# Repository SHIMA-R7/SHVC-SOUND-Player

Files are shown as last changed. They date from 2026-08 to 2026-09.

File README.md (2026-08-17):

# SHVC-SOUND スタンドアロンプレイヤー

Arduino Uno R3 / Nano (ATmega328P・5Vロジック) で SHVC-SOUND(スーファミ音源モジュール: S-SMP + S-DSP + ARAM + DAC)を駆動し、
`.spc` ファイルを実チップで再生するプロジェクト。音声は TDA7053A(ステレオBTL)で増幅し3.5mmジャックへ出力する。

## 構成

| ディレクトリ | 内容 |
|---|---|
| `SHVC-SOUND-KiCad_project/` | 基板設計(KiCad)。スキーマ・PCB・カスタムフットプリント |
| `SHVC-SOUND_python/` | 再生ソフト一式 |
| `SHVC-SOUND_python/spc_gui.py` | **GUIアプリ**(Tkinter製)。プレイリスト再生・音量調整・ROM解析 |
| `SHVC-SOUND_python/spc_play.py` | PC側。`.spc` を解析しシリアル経由でArduinoへ転送する(CLI/GUI共用) |
| `SHVC-SOUND_python/rom_tools.py` | スーファミROMの内部ヘッダ解析(マッパ判別・チェックサム検証) |
| `SHVC-SOUND_python/spc_uploader/` | Arduino側。シリアルコマンドをSPC700 IPL ROMプロトコルへ変換する |
| `SHVC-SOUND_python/hw_selftest/` | Arduino単体で動く自己診断。PCなしでノイズを鳴らして配線を検証する |
| `docs/minimal-bringup.md` | 最小構成での実機立ち上げ手順と配線表 |

## まず実機で音を確認する

いきなり `spc_play.py` を試す前に、アンプと12V系を外した最小構成で
`hw_selftest/hw_selftest.ino` を走らせる。ハードの問題か転送ソフトの問題かが一発で切り分けられる。
手順と配線表は [docs/minimal-bringup.md](docs/minimal-bringup.md) を参照。

## GUIアプリ

```bash
python spc_gui.py
```

- プレイリストに `.spc` をまとめて登録して再生。ID666タグ(曲名・ゲーム・作曲者)を表示
- DSP音量倍率とアンプPWM音量をスライダーで調整
- 転送はワーカースレッドで実行され、進捗バーとログをリアルタイム表示。中止も可能
- **フォルダ監視**: エミュレータのSPC出力先を指定しておくと、新しくダンプされた
  `.spc` を自動でプレイリストに追加する
- ROM解析タブ: 吸い出したROMのタイトル・マッパ(LoROM/HiROM/ExHiROM)・容量・
  リージョン・チェックサムを表示

### ROMからのSPC抽出について

**ROMの中に `.spc` は入っていない**ため、直接抽出はできない。
`.spc` はSPC700が曲を再生中の ARAM 64KB + DSPレジスタ + CPUレジスタの
スナップショットであり、ROMにあるのはサウンドドライバ・BRRサンプル・
シーケンスデータがバラバラに格納されたもの。ARAMの完成イメージは
ゲームを実際に起動して初めて組み上がる。

実用的な手順は、SPCダンプ機能を持つエミュレータ(Mesen2、bsnes/higan、
一部のSnes9xビルド)でROMを動かし、曲の再生中にダンプすること。
出力先をGUIの「フォルダを監視」に指定しておけば、ダンプした瞬間に
プレイリストへ入って実機で鳴らせる。

## CLIでの使い方

Arduino IDE で `spc_uploader/spc_uploader.ino` を書き込み、以下を実行する。

```bash
python spc_play.py COM3 song.spc
```

`pyserial` が必要:

```bash
pip install pyserial
```

診断用フラグ: `--test`(強制ノイズ再生)、`--skip-bulk`、`--low-addr`、`--only-stub`

## 配線 (Arduino ⇔ SHVC-SOUND 24pin)

| Arduino | SHVC-SOUND pin | 信号 |
|---|---|---|
| D2-D9 | 7-14 | D0-D7 |
| A0 | 3 | A0 |
| A1 | 4 | A1 |
| A2 | 5 | /WR |
| A3 | 6 | /RD |
| A4 | 15 | /RESET |
| D10 | 20 | /MUTE(常時HIGH固定) |
| - | 2 / 1 | CS→+5V / /CS→GND 直結 |
| - | 18, 24 | VCC, VS → +5V |
| - | 19, 23 | GND |
| - | 21, 22 | Audio-L / Audio-R → アンプ入力 |

ロジック系(5V)とアンプ系(12V)は別電源。Arduinoのレギュレータからアンプ用12Vを取らないこと。

## 既知の問題

- **復元スタブが曲データを上書きする**: `spc_play.py` のDSP復元スタブは約800バイトあり `$FFC0` 直下(≒`$FC9B`)に配置されるが、
  この領域はメインRAM転送範囲(`$0100-$FFBF`)と重なるため曲データを約800バイト破壊する。
  この領域をサンプルやエコーバッファに使う曲ではノイズが出る。エコーバッファ領域への配置か、スタブのループ化による小型化が要検討。
- **基板のDRC違反が未修正**: シルク重なり2件、シルクが銅箔にかかる6件、フットプリント型不一致1件、ライブラリ不一致1件。
- 実機での動作確認は未完了。
- **基板のSHVC-SOUNDフットプリントに1番ピンの表示が無い**: `SHVC-SOUND-MB.kicad_mod` は
  パッド24個すべてが丸、シルクにピン番号も1番マーカーも無い(リファレンス指定子のみ)。
  コネクタ自体にキーが無く逆挿しできてしまうため、シルクに `1` の印字と極性マークを追加すべき。
- **基板はArduino Nanoフットプリント**(`Module:Arduino_Nano_WithMountingHoles`)。
  Uno R3はピン互換だがフットプリントが合わないため、基板に載せる場合は要変更。ジャンパ配線での検証には支障なし。

## ライセンス / 帰属

基板設計の一部は [OpenSFC](https://github.com/starlightk7/OpenSFC)(© 2025 starlightk7、CERN-OHL-S)に由来する。
詳細と再頒布時の義務は `SHVC-SOUND-KiCad_project/SHVC-SOUND-KiCad/THIRD_PARTY_NOTICE_OpenSFC.txt` を参照。
公開・頒布する場合は CERN-OHL-S 3.3 に従い、改変内容の要約を同NOTICEに追記すること。

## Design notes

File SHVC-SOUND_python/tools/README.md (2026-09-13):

# tools — 実機向けの補助ツール

`spc_realtime.ino` を書き込んだ Arduino + SHVC-SOUND で使う。
いずれも `SHVC-SOUND_python` の `midi2spc` / `spc_play` を読み込むので、このフォルダに置いたまま実行する。

## 録音をそのまま鳴らす(BRRストリーミング)

| ツール | 内容 |
|---|---|
| `pcm_stream.py` | 録音をBRRに変換し、ARAMのリングバッファへ書き足しながら最後まで鳴らす。`--loop-whole` で短い音声をS-DSPだけでループ。`--selftest` でSPC700側ドライバをシミュレータ検証 |
| `pcm_clip_test.py` | ARAMに収まる数秒だけを一括転送して鳴らす(実現性確認用) |
| `zundamon_talk.py` | VOICEVOX(ずんだもん)でセリフを合成し、`pcm_stream.py --loop-whole` で鳴らす |
| `morning_call.py` | 指定時刻にモーニングコール → 曲のストリーミング再生(待機中はアイドルスリープを抑止) |

```bash
python pcm_stream.py song.wav --rate 8000 --peak 0.8
```

仕組み: ARAM `$0400-$FEFA` をBRRのリングバッファにし、ボイス0がバッファ末尾(loop+end)で先頭へ戻り続ける。
SPC700上のドライバ(`PCM_DRIVER`、IPLで `$0200` へ転送)は、ホストの `$F4` の変化を合図に `$F7` のコマンドで分岐する。

| `$F7` | 動作 |
|---|---|
| 0 | DSPレジスタ書き込み(`$F5`=レジスタ, `$F6`=値) |
| 1 / 2 | 1 / 2バイトをリングバッファへ書き、ポインタ(`$02-$03`)を進める |
| 3 | ポインタを返す |
| 4 | DSPレジスタ読み出し |
| 5 | ポインタ設定(起動直後、IPLジャンプの残りポート値を指示と誤認して1回書いてしまうので必ず合わせ直す) |
| 6 | ポインタ位置の1バイトを返す(読み返し検査用) |

Arduino側コマンド: `CMD_PCMCHUNK`(0x0C) / `CMD_DRVQUERY`(0x0D) / `CMD_DRVPEEK`(0x0E)。

注意: `midi2spc/brr.py` の予測フィルタの丸めは実機S-DSPと完全には一致しない。長い録音では `--filter0`(予測なし)も選べる。

VOICEVOXエンジンはリポジトリに含めない。`tools/voicevox_engine/` に展開するか、`--engine-dir` / 環境変数 `VOICEVOX_ENGINE_DIR` で場所を指定する。
音声を公開する場合はクレジット「VOICEVOX:ずんだもん」が必要。

## 自動採譜・MIDIの整理

| ツール | 内容 |
|---|---|
| `midi_reduce.py` | トラックを選んでチャンネル・音色を振り直す(オーケストラ譜の書き出し向け) |
| `separate_transcribe.py` | Demucsでパート分離 → Basic Pitchでパートごとに採譜(チューニング補正つき) |
| `score_transcribe.py` | 拍の升目にそろえてメロディ・和音・ベースを起こす |
| `vocal_melody.py` | 分離したボーカルからpYINで主旋律を取る |
| `midi_arrange.py` / `midi_thin.py` | 採譜結果をメロディ/和音/ベースに整理 / 重ねと音数を間引く |

楽器演奏の録音ならそこそこ使えるが、歌入りのポップスや合唱は崩れやすい。
必要なもの: basic-pitch(ONNX), librosa, pretty_midi, demucs + torch(CPU), soundfile。

## 診断

| ツール | 内容 |
|---|---|
| `port_probe.py` | リセット前後の `$F4-$F7` を読む(配線の化けの確認) |
| `probe_retry.py` | 正常な値が読めるまで繰り返す |

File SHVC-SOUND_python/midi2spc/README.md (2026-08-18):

# midi2spc — MIDIをSHVC-SOUND(SPC700 / S-DSP)で鳴らす

MIDIファイルを、スーファミ音源(S-DSP)の制約に落とし込んで演奏するツール。
**PC上のソフトウェアモデル**でも、**実機のSHVC-SOUND**でも鳴らせる。

## 使い方(GUI)

配布用の実行ファイルは `dist/MIDI-to-SHVC-SOUND.exe`。Pythonのインストールは不要。

ソースから起動する場合:

```bash
python midi_gui.py
```

タブ構成:

- **変換・再生** — MIDIを選んで「変換」、そのまま再生 / WAV保存。音量倍率などの設定もここ
- **DSPイベント** — 変換結果として S-DSP に送るレジスタ操作の時系列を一覧表示
- **音色バンク** — BRRサンプルの一覧。選んで「試聴」でドレミが鳴る

起動時に音色バンクのBRRエンコード(十数秒)が走る。終わるまで「変換」は押せない。

exeを作り直すとき:

```bash
python -m PyInstaller --noconfirm --onefile --windowed --name "MIDI-to-SHVC-SOUND" --collect-all sounddevice midi_gui.py
```

## 使い方(コマンドライン)

```bash
python -m midi2spc song.mid
```

```bash
python -m midi2spc song.mid -o out.wav
```

```bash
python -m midi2spc song.mid --dump-events
```

```bash
python -m midi2spc --list-instruments
```

主なオプション:

| オプション | 意味 |
|---|---|
| `-o FILE` | WAVに書き出す(省略時はその場で再生) |
| `--master N` | ボイス音量の全体倍率 0.0-1.0(既定 0.55)。和音が多い曲で歪むなら下げる |
| `--gain N` | 出力全体のゲイン |
| `--tail N` | 曲末尾に足す余韻の秒数 |
| `--dump-events [N]` | S-DSPに送るイベント列を表示 |
| `--no-audio` | 音を出さず変換だけ確認 |

必要なもの: `numpy`(必須)、`sounddevice`(その場で再生する場合のみ)。

## 実機で鳴らす

### 1. Arduinoにファームウェアを書き込む

`spc_realtime/spc_realtime.ino` を書き込む。これは `spc_uploader.ino` の**上位互換**で、
従来の .spc 転送コマンドもそのまま残っているので `spc_gui.py` / `spc_play.py` も
このファームのまま動く。ピン配置は従来と同一。

```bash
arduino-cli compile --fqbn arduino:avr:nano spc_realtime
arduino-cli upload -p COM3 --fqbn arduino:avr:nano spc_realtime
```

### 2. 鳴らす

GUIの「実機で再生」欄でシリアルポートを選び、変換後に「実機へ転送して再生」。
コマンドラインなら:

```bash
python -m midi2spc song.mid --port COM3
```

### 実機再生時に起きること

1. SPC700をリセットしてIPL ROMの転送モードに入る
2. BRRサンプル(約13KB)・サンプルディレクトリ・常駐ドライバをARAMへ転送
3. 常駐ドライバへジャンプ
4. DSPを初期化(エコー無効・DIR設定・マスター音量)
5. レジスタ書き込みイベントをArduinoへストリーム送信

ARAMのメモリマップ:

| アドレス | 内容 |
|---|---|
| `$0200-$0216` | 常駐ドライバ(23バイト) |
| `$0300-$034F` | サンプルディレクトリ(1音色4バイト × 20) |
| `$0400-$3900` | BRRサンプル本体(約13KB) |

### 常駐ドライバ(23バイト)

S-DSPのレジスタはSPC700からしか触れず、ホスト(Arduino)から見えるのは
`$F4-$F7` の4バイトの窓だけ。そこで「`$F5`のレジスタ番号と`$F6`の値をDSPへ
書き写すだけ」のループをSPC700に常駐させ、Arduinoはその窓越しに指示を出す。

```asm
        clrp                    ; ダイレクトページを$00xxに固定
        mov  x,#$00
        mov  $F4,x              ; ACKラッチを初期化
loop:   cmp  x,$F4              ; ホストからの新しい指示待ち
        beq  loop
        mov  x,$F4              ; 新しいシーケンス値
        mov  a,$F5              ; DSPレジスタ番号
        mov  $F2,a              ;   -> DSPADDR
        mov  a,$F6              ; 書き込む値
        mov  $F3,a              ;   -> DSPDATA
        mov  $F4,x              ; ACK(シーケンス値を返す)
        bra  loop
```

曲の解釈はすべてPC側に残るので、SPC700側はこれで足りる。
**音楽ドライバをアセンブリで書く必要はない**のがこの構成の要点。

### 演奏タイミング

発音タイミングはArduinoが持つ。PCは4バイトのレコード
`[待ち時間LE16(100µs単位)][レジスタ番号][値]` を送り、Arduinoは48段の
リングバッファに積んで `micros()` で時刻どおりに実行する。待ち時間は
前のイベントの**予定時刻**から積み上げるので、誤差が累積してテンポがずれない。

PCが送りすぎないよう、Arduinoは1レコード消化するごとにクレジットバイトを返す。
PCは32レコードまで先行送信できる(Arduinoの受信バッファ64バイトとリングバッファ
48段の両方に収まる値)。

## 設計

```
song.mid
   │  smf.py          SMFパーサ(依存ライブラリなし)      ← midi_gui.py / __main__.py が呼ぶ
   ▼
MIDIイベント列
   │  engine.py       ★変換の本体
   ▼
S-DSPレジスタ操作イベント列
   │
   ├─ render.py       S-DSPのソフトウェアモデル → PCで音を出す
   └─ hardware.py     Arduino経由で実チップを鳴らす
```

`engine.py` が出すのは「どのボイスに、どのサンプルを、どのピッチ・音量・ADSRで
キーオンするか」という時系列で、これは実機のS-DSPレジスタ書き込みと1対1に対応する。
つまり `render.py` を差し替えれば、同じ変換結果をそのままハードウェアに流せる。

音色(`instruments.py`)も飾りではなく、実際に **BRR(4bit ADPCM)にエンコードして
デコードし直した波形**を鳴らしている。実機に載せるときはこの `brr_data` を
そのままARAMへ転送すればよい。バンク全体で約14KB、64KBのARAMに十分収まる。

## 再現していること / していないこと

再現している:

- BRRによる4bit量子化(実機と同じ量子化ノイズが乗る)
- 32kHz固定のサンプルレートと4タップ補間による高音のなまり
- **同時発音8ボイス**の制限と、足りないときの音の奪い合い
- 14bit PITCHレジスタ、ADSRエンベロープ、符号付き8bitのVOLL/VOLR
- MIDI側は NoteOn/Off、プログラムチェンジ、CC7/CC10/CC11/CC64、ピッチベンド、テンポチェンジ

再現していない(意図的な簡略化):

- サイクル精度のDSP動作(合成は「ノート単位」でまとめて行う)
- エコー / FIRフィルタ / ピッチモジュレーション / ノイズジェネレータ
- 補間テーブルは実機の512エントリ表そのものではなくガウス窓による近似
- ADSRのDECAY/SUSTAINは、実機の「周期ごとに `env -= (env>>8)+1`」を
  1サンプルあたりの減衰係数に直した閉じた形で計算している(形は同じ)

## テスト

```bash
python test_midi2spc.py
```

43件。実機がなくても確かめられるところを固めてある。特に常駐ドライバは
手でアセンブルした生バイト列なので、簡易SPC700シミュレータ(テスト内に同梱)で
実際に実行して、ACKハンドシェイク・シーケンス値の一周・キーオン1音ぶんの
レジスタ列が正しく届くことを検証している。

**実機での再生は2026-08-18に確認済み。** Arduino Uno + SHVC-SOUND で
rydeen.mid(9240ノート / 約4分半 / DSPレジスタ書き込み120120回)が
最後まで正常に再生できた。

## 実機で音が出ないときの切り分け

1. `spc_gui.py` で .spc が再生できるか — できなければ配線かバスタイミングの問題で、
   MIDI側とは無関係
2. GUIのログで「ドライバへジャンプ」の後にエラーが出るか —
   `常駐ドライバが応答しません` なら、ジャンプ自体かドライバの動作の問題
3. 転送は通るのに無音 — DSPの初期化(FLGのミュート解除、マスター音量)か、
   BRRサンプルのディレクトリ位置(`DIR`レジスタ)を疑う
4. 音は出るがノイズまみれ — エコーがARAMのサンプル領域を上書きしている可能性。
   `initial_dsp_writes()` がFLGのbit5(エコー書き込み禁止)を立てているか確認する

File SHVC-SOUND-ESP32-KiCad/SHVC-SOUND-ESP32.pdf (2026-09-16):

1 | 2 | 3 | 4 | 5 | 6 | 7 | 8
1 | 2 | 3 | 4 | 5 | 6 | 7 | 8

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
Size: A3 | Rev: 0.1 | F Date:
KiCad E.D.A. 10.0.6 | Id: 1/1

## Title: SHVC-SOUND Player ESP32

File: SHVC-SOUND-ESP32.kicad_sch

Sheet: /

C7

470n C6
470n

V+ 1 GND 2

J3

12V in (USB-PD)

C1
100u R6
10k | C3

100n

R1
330
SLEEVE 1 | RING
2 | RING_SW
3 | TIP

4
TIP_SW

5

# J1 PJ-324M

R8
10k

R10

10 C11

470u | R2

330 GND 1
VCC 2
A0 3
A1 4 | WR 5 | RD 6 | D0 7 | D1 8 | D2 9 | D3 10 | D4 11 | D5 12 | D6 | 13 D7 | 14 RESET | 15 NC | 16 NC | 17
VCC | 18 GND | 19 MUTE | 20
AUDIO_L | | 21
AUDIO_R | 22 GND | 23
VCC | | 24

J4

SHVC-SOUND module

C12
100u | R5
5.6k | C5 10u

R7
10k | OE1 1

A1 2
A2 3
A3 4
A4 5
A5 6
A6 7
A7 8
A8 9 | GND 10
Y8 | 11 Y7 | 12 Y6 | 13 Y5 | 14 Y4 | 15 Y3 | 16 Y2 | 17 Y1 | 18 OE2 19
VCC 20 | U2
74HCT541N (data write) | C8
100n C10

100n

EN 1
IO36 2
IO39 3
IO34 4
IO35 5
IO32 6
IO33 7
IO25 8
IO26 9
IO27 10
IO14 11
IO12 12
IO13 13 GND 14

VIN 15

IO23 | | 16
IO22 | | 17
TX0/IO1 | 18 RX0/IO3 | 19
IO21 | | 20
IO19 | | 21
IO18 | | 22
IO5 | | 23
TX2/IO17 | 24 RX2/IO16 | 25
IO4 | | 26
IO2 | | 27
IO15 | 28 GND | 29
3V3 | 30 U1

ESP32 DevKit V1 (30pin)

R9

# 10k DIR 1

A1 2
A2 3
A3 4
A4 5
A5 6
A6 7
A7 8
A8 9 | GND 10 | B8 | 11 B7 | 12 B6 | 13 B5 | 14 B4 | 15 B3 | 16 B2 | 17 B1 | 18 OE 19
VCC 20 | U4
74LVC245N (data read, DIR=B->A) | C2
100u C4

220u P1 1
VC_A 2 P3 3

IN_A 4
VP 5
IN_B 6 | GND 7
VC_B 8 | OUT_A | 9 GND | 10 P11 | 11 GND | 12 GND | 13 GND | 14 P15 | 15 OUT_B | 16 U6

TDA7053A C13

10u OE1 1

A1 2
A2 3
A3 4
A4 5
A5 6
A6 7
A7 8
A8 9 | GND 10
Y8 | 11 Y7 | 12 Y6 | 13 Y5 | 14 Y4 | 15 Y3 | 16 Y2 | 17 Y1 | 18 OE2 19
VCC 20 | U3
74HCT541N (control) | +VIN 1 | GND 2
VOUT | 3 U7 M78AR05-0.5 C9
100n | D1
1N5819

# GND +5V SHVC_D6

SHVC_D7

SHVC_RESET AUDIO_L AUDIO_R | AMP_IN_R

AMP_VC

AMP_IN_L AUDIO_L AMP_IN_L | AUDIO_R | AMP_VP +12V GND +12V | AMP_VC GND

# A1_3V3 D1_3V3 D0_3V3 GND +5V GND

RESET_3V3
VOL_PWM
RD_3V3 +5V | D3_3V3 D2_3V3 OE_W

# GND +3V3 WR_3V3 D7_3V3 D6_3V3 D5_3V3 D4_3V3

A0_3V3 | OE_R

D7_3V3 +5V GND

GND OE_R

# D0_3V3 D1_3V3 D2_3V3 D3_3V3 D4_3V3 D5_3V3 D6_3V3 D7_3V3 +3V3

SHVC_D0

SHVC_D2
SHVC_D3
SHVC_D4
SHVC_D5
SHVC_D6
SHVC_D7 | +5V GND

GND

SHVC_A1

SHVC_A0 +3V3

SHVC_D3
SHVC_D4

# SHVC_D5 +5V GND

SHVC_WR
SHVC_RD
SHVC_D0
SHVC_D1
SHVC_D2

SHVC_A0
SHVC_A1
SHVC_WR

SHVC_D1

SHVC_RESET GND RESET_3V3 | D1_3V3 OE_R | +3V3 | GND

SHVC_D0
SHVC_D1
SHVC_D2

SHVC_D3 +5V D2_3V3 D3_3V3 D4_3V3 D5_3V3 D6_3V3 OE_W

GND

D0_3V3

SHVC_D4
SHVC_D5
SHVC_D6
SHVC_D7

# SHVC_RD +3V3 OE_W +3V3

AMP_OUT_R

GND

GND | OUT_L_RC

GND
JACK_L

# JACK_R JACK_L AMP_OUT_L OUT_L_RC

GND

GND

AMP_OUT_L GND | OUT_R_RC | JACK_R AMP_OUT_R | OUT_R_RC GND AMP_VP GND | AMP_VP VOL_PWM

AMP_VP
AMP_IN_R
GND
AMP_VC AMP_VC GND +12V | +5V GND +12V | AMP_VC

GND

# GND +5V GND

A0_3V3

A1_3V3 WR_3V3 RD_3V3 RESET_3V3 GND

GND | GND +5V GND

GND

REG_5V +5V REG_5V | +5V SHVC-SOUND player - ESP32 version (74HCT541N x2 + 74LVC245N + TDA7053A)

Data bus: U2(HCT541, write 3.3V->5V) and U4(LVC245 DIR=GND, read 5V->3.3V) are in parallel.

Firmware must never assert OE_W and OE_R (both active low) at the same time.

R7/R8 keep both buffers disabled while the ESP32 boots. R9 keeps /RESET inactive.

ESP32 DevKit V1 30pin (DOIT type). GPIO16/17 are PSRAM on WROVER boards - use WROOM-32.

Amp circuit copied from SHVC-SOUND-KiCad (Arduino version). R5 3.3k -> 5.6k for 3.3V PWM, ferrite bead FB1 -> R10 10 ohm.

TDA7053A pin names are inferred from the existing schematic; check the datasheet.

12V (USB-PD) -> U7 M78AR05-0.5 -> D1 1N5819 -> +5V. USB on ESP32 can stay connected (board has VIN diode - check yours).

Tie all grounds together at one point. Use electrolytics with correct polarity for C1/C2/C4/C5/C11/C12. | C13
10u | U7 M78AR05-0.5 +VIN 1 | GND 2
VOUT | 3 C9
100n

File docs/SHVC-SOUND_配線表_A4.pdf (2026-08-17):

# SHVC-SOUND 最小構成 配線表

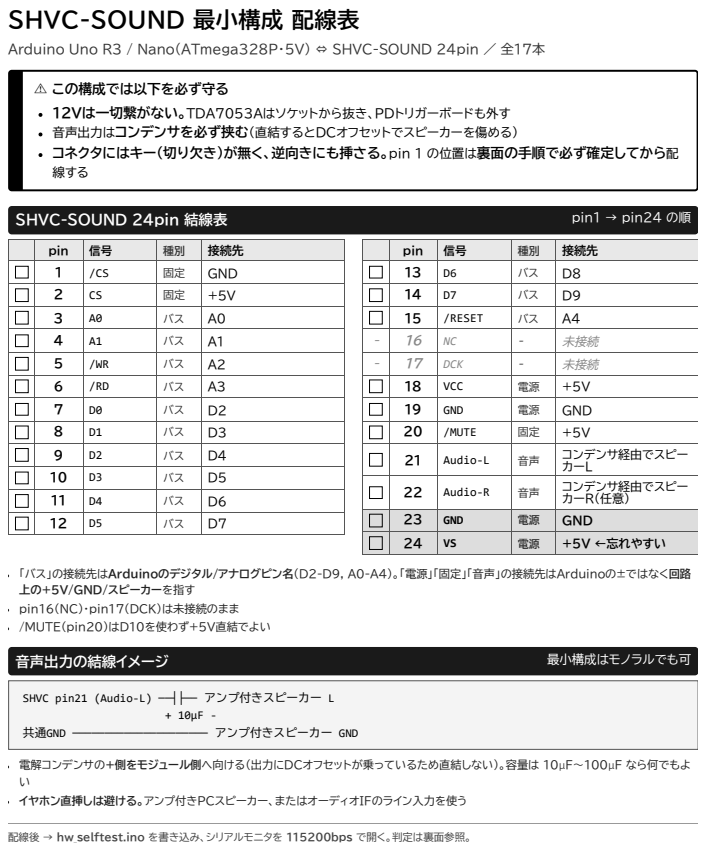
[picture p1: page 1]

Arduino Uno R3 / Nano(ATmega328P・5V) ⇔ SHVC-SOUND 24pin ／ 全17本

12Vは一切繋がない。TDA7053Aはソケットから抜き、PDトリガーボードも外す
音声出力はコンデンサを必ず挟む(直結するとDCオフセットでスピーカーを傷める)
コネクタにはキー(切り欠き)が無く、逆向きにも挿さる。pin 1 の位置は裏面の手順で必ず確定してから配
線する

10 | D3 | バス | D5
11 | D4 | バス | D6
12 | D5 | バス | D7

22 | Audio-R | 音声 | コンデンサ経由でスピー カーR(任意)

23 | GND | 電源 | GND

24 | VS | 電源 | +5V ←忘れやすい

「バス」の接続先はArduinoのデジタル/アナログピン名(D2-D9, A0-A4)。「電源」「固定」「音声」の接続先はArduinoの±ではなく回路
上の+5V/GND/スピーカーを指す
pin16(NC)・pin17(DCK)は未接続のまま
/MUTE(pin20)はD10を使わず+5V直結でよい

電解コンデンサの+側をモジュール側へ向ける(出力にDCオフセットが乗っているため直結しない)。容量は 10µF〜100µF なら何でもよ
イヤホン直挿しは避ける。アンプ付きPCスピーカー、またはオーディオIFのライン入力を使う

配線後 → hw_selftest.ino を書き込み、シリアルモニタを 115200bps で開く。判定は裏面参照。

# ① 1番ピンの確定 ─ 配線より先にやる

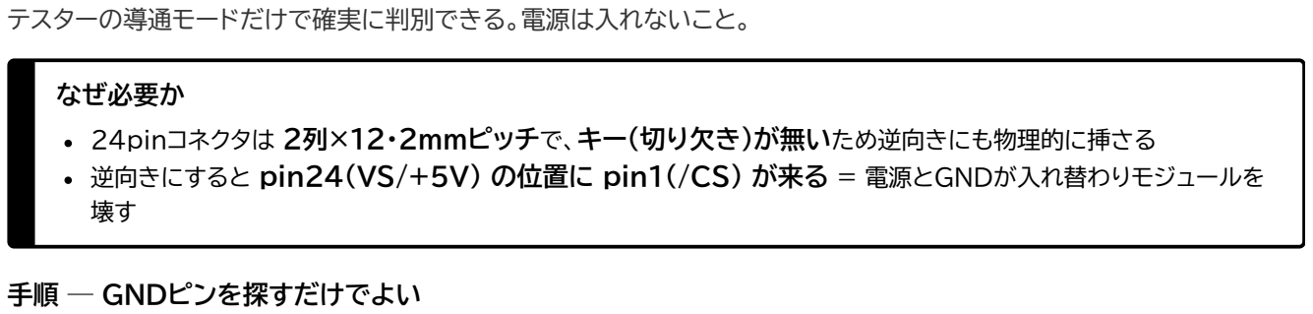
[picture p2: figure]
テスターの導通モードだけで確実に判別できる。電源は入れないこと。; なぜ必要か; 24pinコネクタは 2列×12・2mmピッチで、キー(切り欠き)が無いため逆向きにも物理的に挿さる; 手順 ─ GNDピンを探すだけでよい

逆向きにすると pin24(VS/+5V) の位置に pin1(/CS) が来る = 電源とGNDが入れ替わりモジュールを

手順
テスターを導通(ブザー)モードにし、片方のプローブをモジュールの金属シールド、または基板の大きなベタ面に当てて 固定する

もう片方で24本すべてを順に当たり、導通する(鳴る)ピンを全部書き出す
導通するのは pin19 と pin23 の2本だけ。この2本が下の特徴に一致するはず

GND 2本が示す決定的な特徴

奇数列 | 23 GND | 21 Audio-L | 19 GND | 17 | 15 | … | 5 | 3 | 1 | ← pin 1/2 側
偶数列 | 24 | 22 | 20 | 18 | 16 | … | 6 | 4 | 2

↑ 導通するのはこの2本だけ
この端が 23/24 側 | この側には導通するピンは1本も無い
見つかった状態 | 結論
導通する2本が同じ列にあり、間に1 本挟んで並び、片方がコネクタの端 | 端にある方が pin23／間の1本が pin21(Audio-L)／もう片方が pin19。 その列が奇数列、その端が23/24側 → 反対の端が pin1/2で、pin1 は GND と 同じ列
導通するピンが3本以上ある / 上の 並びにならない | ここで止める。基準にしたベタ面がGNDでない可能性がある。別の基準点で取り直 す

反対の端(pin1/2側)には導通するピンが1本も無いことも併せて確認する。GNDの並びは片側にしか現れないので、これで向きが一意に 決まる
pin1(/CS)は入力ピンなので、モジュール内部でGNDに落ちてはいない。誤検出にはならない

向きが確定したら、油性ペンでモジュールのpin1側に印を付けておく。

# ② 診断結果の読み方

hw_selftest.ino / シリアルモニタ 115200bps ／ 何かキーを送ると再実行

まず結論から

シリアルモニタの表示 | 意味
全部 [OK] + ノイズが鳴る | ハードは完動。音が出ない原因は spc_play.py 側にある
全部 [OK] なのに無音 | 転送も実行も成功している。原因は音声出力側だけに絞れる。コンデンサの 極性 / スピーカーの音量 / pin20(/MUTE)がHIGHか を確認
[1] で止まる ─ port0/port1 が $AA/$BB にならない

モジュールが起動していない。表示された値で原因が切り分けられる。

読めた値 | 疑う所
$FF | モジュールが応答していない。VCC(18)とVS(24)の両方に5Vが来ているか / GND(19,23)が Arduinoと共通か / /CS(1)=GND・CS(2)=+5V か / /RESET(15)がA4に繋がっているか
$00 | データバスがGNDに落ちている。D0-D7(pin 7〜14)の配線を確認

毎回違う値 /RD(A3) か /WR(A2) の配線ミス、または結線が浮いている

[2] で止まる ─ 1ブロック目の転送に失敗

リセットは通るのに書き込みが通らない。D0-D7 のどれかが入れ替わっているか浮いている。A0(pin3)/A1(pin4) の配線も確認する。

[3] で止まる ─ 2ブロック目の転送に失敗

1ブロック目は通るのに2ブロック目で落ちる = ブロック切り替えのタイミング問題。配線自体は概ね正しい。ジャンパ線を短くする、電源に パスコン(0.1µF)を追加する。

[5] でマーカーが $99 にならない

転送は通ったがジャンプが失敗している。

よくある落とし穴

VS(pin24)の繋ぎ忘れ — VCCだけ繋いで動かない例が最も多い GNDが共通でない — 外部電源を併用する場合は必ずArduinoのGNDと繋ぐ ジャンパ線が長い — 20cm級を使うとバスが不安定になる。10cm以下にする

音声出力の直結 — DCオフセットでスピーカーを傷める。必ずコンデンサを挟む D0-D7の順序間違い — D2→pin7 から始まる。D0→pin7 ではない

SHVC-SOUND スタンドアロンプレイヤー ／ 詳細は docs/minimal-bringup.md

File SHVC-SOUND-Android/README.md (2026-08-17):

# SHVC-SOUND Android アプリ (作業中)

PCを使わず、Android端末とArduinoをUSB(OTG)で直結して`.spc`を再生するためのアプリ。
`SHVC-SOUND_python/spc_play.py` と同じロジックをKotlinへ移植している。

実体のAndroid Studioプロジェクトは `C:\Users\<user>\AndroidStudioProjects\SHVCSoundPlayer`
にある。このフォルダはソースコードの参照・バックアップ用。

## 進捗

- [x] プロジェクト作成 (Empty Views Activity, Kotlin, minSdk 26, package `com.shvc.soundplayer`)
- [x] `usb-serial-for-android` 依存関係の追加 (JitPack経由)
- [x] `AndroidManifest.xml` に `android.hardware.usb.host` の feature 宣言を追加
- [x] `SpcFile.kt` — `.spc`ファイル解析 (Python版 `SpcFile` クラス相当)
- [x] `SpcController.kt` — Arduinoとの通信プロトコル (`spc_uploader.ino`と同一プロトコル)
- [x] `StubBuilder.kt` — DSPレジスタ復元コード生成 (Python版 `build_final_stub`/`boost_master_volume`相当)
- [x] 上記3ファイルのビルド確認 (`BUILD SUCCESSFUL`、実機Android Studioで確認済み)
- [ ] `MainActivity.kt` + レイアウト(UI)
- [ ] USBデバイス接続・パーミッション処理
- [ ] 実機での動作確認(Arduino実機とのUSB直結)

## 既知の注意点

- `UsbSerialPort.write()` はこのバージョンのライブラリでは戻り値なし(書き込みバイト数を
  返さない)。全バイト書き終わるかタイムアウトで例外を投げるまでブロックする前提で実装している。
- プロトコル定数(CMD/ACK値、PING_INTERVAL=64、ボーレート500000)は
  `SHVC-SOUND_python/spc_uploader/spc_uploader.ino` と完全に一致させること。
  どちらか一方だけ変更すると通信できなくなる。

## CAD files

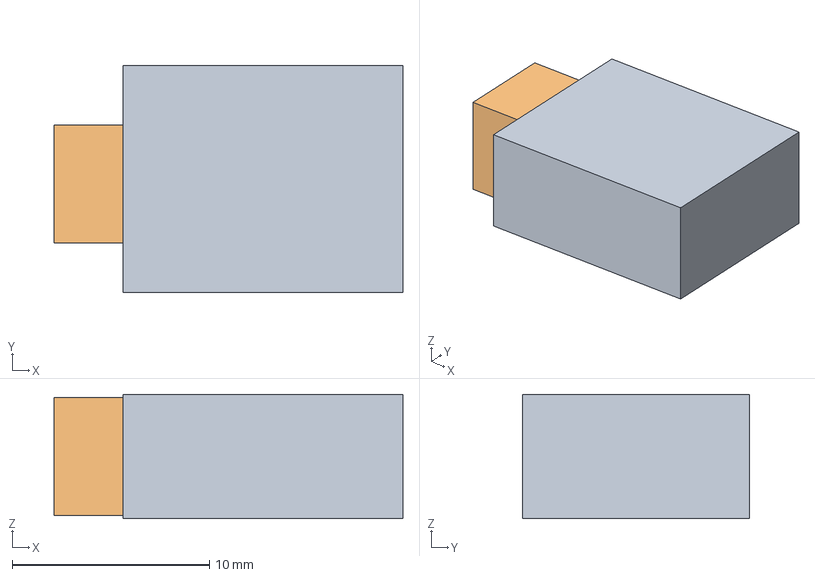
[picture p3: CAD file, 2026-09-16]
SHVC-SOUND-ESP32-KiCad/3d/pj-324m.step
17.7 x 11.5 x 6.30 mm

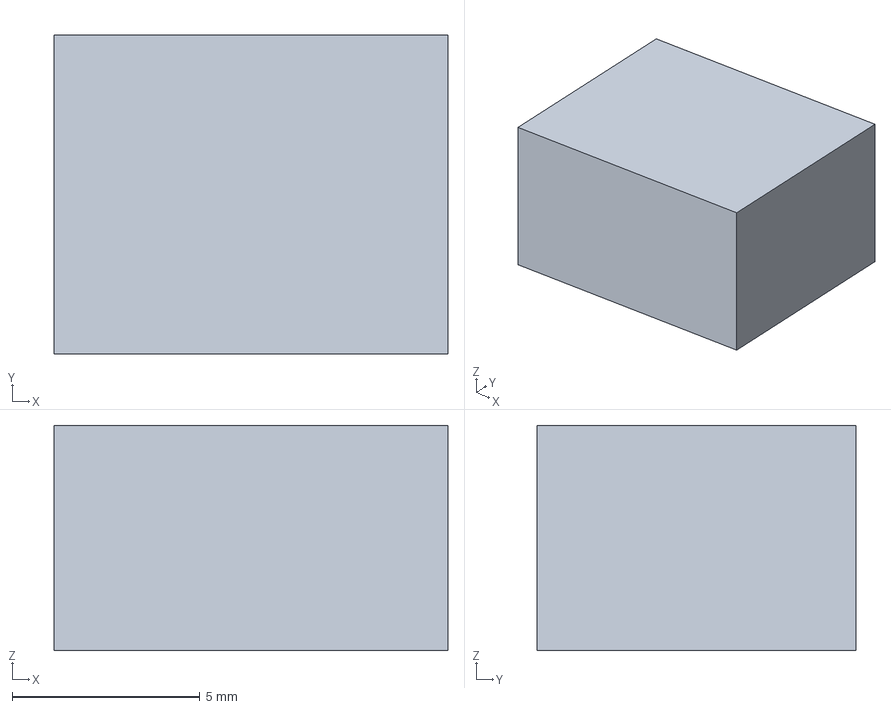
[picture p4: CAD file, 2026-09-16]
SHVC-SOUND-ESP32-KiCad/3d/pd_module.step
10.5 x 8.50 x 6.00 mm

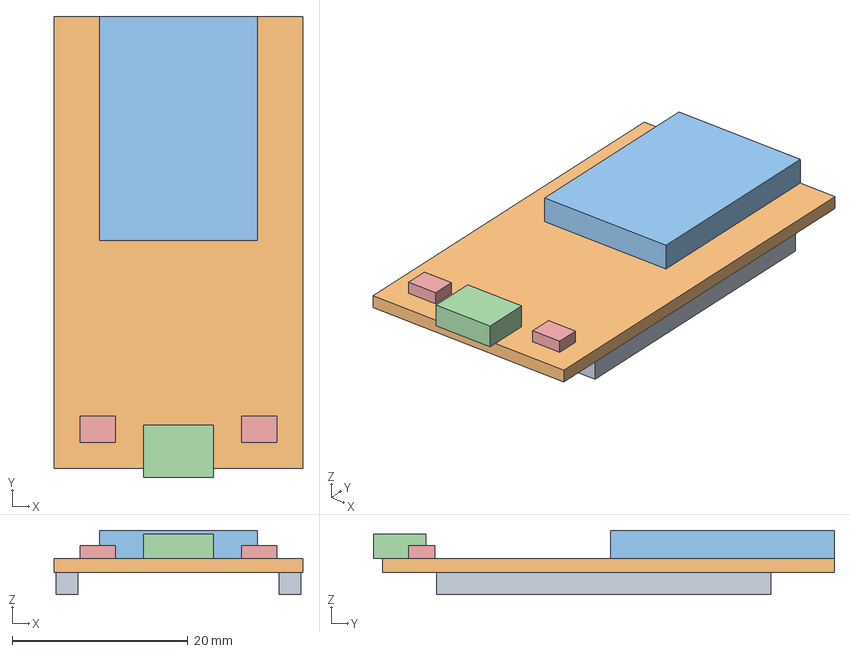
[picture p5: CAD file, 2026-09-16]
SHVC-SOUND-ESP32-KiCad/3d/esp32_devkit_v1_30.step
28.3 x 52.5 x 7.30 mm

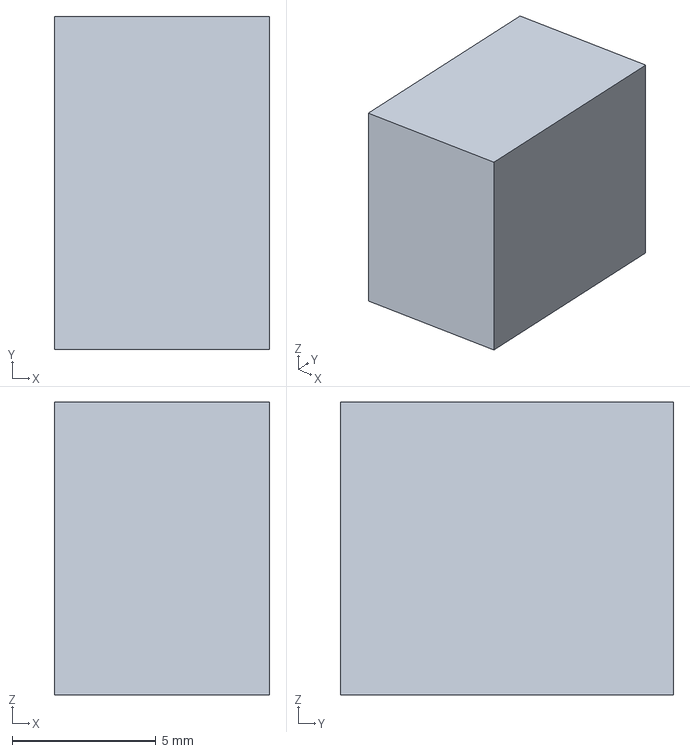
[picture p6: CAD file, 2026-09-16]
SHVC-SOUND-ESP32-KiCad/3d/dcdc_sip3.step
7.50 x 11.6 x 10.2 mm

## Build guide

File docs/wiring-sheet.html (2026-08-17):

# SHVC-SOUND 最小構成 配線表

Arduino Uno R3 / Nano(ATmega328P・5V) ⇔ SHVC-SOUND 24pin ／ 全17本

⚠ この構成では以下を必ず守る

- 12Vは一切繋がない。TDA7053Aはソケットから抜き、PDトリガーボードも外す
- 音声出力はコンデンサを必ず挟む(直結するとDCオフセットでスピーカーを傷める)
- コネクタにはキー(切り欠き)が無く、逆向きにも挿さる。pin 1 の位置は裏面の手順で必ず確定してから配線する

## SHVC-SOUND 24pin 結線表 pin1 → pin24 の順

| pin | 信号 | 種別 | 接続先
| 1 | /CS | 固定 | GND
| 2 | CS | 固定 | +5V
| 3 | A0 | バス | A0
| 4 | A1 | バス | A1
| 5 | /WR | バス | A2
| 6 | /RD | バス | A3
| 7 | D0 | バス | D2
| 8 | D1 | バス | D3
| 9 | D2 | バス | D4
| 10 | D3 | バス | D5
| 11 | D4 | バス | D6
| 12 | D5 | バス | D7

| pin | 信号 | 種別 | 接続先
| 13 | D6 | バス | D8
| 14 | D7 | バス | D9
| 15 | /RESET | バス | A4
- | 16 | NC | - | 未接続
- | 17 | DCK | - | 未接続
| 18 | VCC | 電源 | +5V
| 19 | GND | 電源 | GND
| 20 | /MUTE | 固定 | +5V
| 21 | Audio-L | 音声 | コンデンサ経由でスピーカーL
| 22 | Audio-R | 音声 | コンデンサ経由でスピーカーR(任意)
| 23 | GND | 電源 | GND
| 24 | VS | 電源 | +5V ←忘れやすい

- 「バス」の接続先はArduinoのデジタル/アナログピン名(D2-D9, A0-A4)。「電源」「固定」「音声」の接続先はArduinoの±ではなく回路上の+5V/GND/スピーカーを指す
- pin16(NC)・pin17(DCK)は未接続のまま
- /MUTE(pin20)はD10を使わず+5V直結でよい

## 音声出力の結線イメージ 最小構成はモノラルでも可

 SHVC pin21 (Audio-L) ──┤├── アンプ付きスピーカー L
                       + 10µF -
 共通GND ───────────────────── アンプ付きスピーカー GND
- 電解コンデンサの+側をモジュール側へ向ける(出力にDCオフセットが乗っているため直結しない)。容量は 10µF〜100µF なら何でもよい
- イヤホン直挿しは避ける。アンプ付きPCスピーカー、またはオーディオIFのライン入力を使う

配線後 → hw_selftest.ino を書き込み、シリアルモニタを 115200bps で開く。判定は裏面参照。

# ① 1番ピンの確定 ─ 配線より先にやる

テスターの導通モードだけで確実に判別できる。電源は入れないこと。

なぜ必要か

- 24pinコネクタは 2列×12・2mmピッチで、キー(切り欠き)が無いため逆向きにも物理的に挿さる
- 逆向きにすると pin24(VS/+5V) の位置に pin1(/CS) が来る = 電源とGNDが入れ替わりモジュールを壊す

### 手順 ─ GNDピンを探すだけでよい

| 手順
| テスターを導通(ブザー)モードにし、片方のプローブをモジュールの金属シールド、または基板の大きなベタ面に当てて固定する
| もう片方で24本すべてを順に当たり、導通する(鳴る)ピンを全部書き出す
| 導通するのは pin19 と pin23 の2本だけ。この2本が下の特徴に一致するはず

### GND 2本が示す決定的な特徴

奇数列 | 23GND | 21Audio-L | 19GND | 17 | 15 | … | 5 | 3 | 1 | ← pin 1/2 側
偶数列 | 24 | 22 | 20 | 18 | 16 | … | 6 | 4 | 2
| ↑ 導通するのはこの2本だけ この端が 23/24 側 | | | この側には導通するピンは1本も無い

見つかった状態 | 結論
導通する2本が同じ列にあり、間に1本挟んで並び、片方がコネクタの端 | 端にある方が pin23／間の1本が pin21(Audio-L)／もう片方が pin19。 その列が奇数列、その端が23/24側 → 反対の端が pin1/2で、pin1 は GND と同じ列
導通するピンが3本以上ある / 上の並びにならない | ここで止める。基準にしたベタ面がGNDでない可能性がある。別の基準点で取り直す

- 反対の端(pin1/2側)には導通するピンが1本も無いことも併せて確認する。GNDの並びは片側にしか現れないので、これで向きが一意に決まる
- pin1(/CS)は入力ピンなので、モジュール内部でGNDに落ちてはいない。誤検出にはならない

向きが確定したら、油性ペンでモジュールのpin1側に印を付けておく。

# ② 診断結果の読み方

hw_selftest.ino / シリアルモニタ 115200bps ／ 何かキーを送ると再実行

### まず結論から

シリアルモニタの表示 | 意味
全部 [OK] + ノイズが鳴る | ハードは完動。音が出ない原因は spc_play.py 側にある
全部 [OK] なのに無音 | 転送も実行も成功している。原因は音声出力側だけに絞れる。コンデンサの極性 / スピーカーの音量 / pin20(/MUTE)がHIGHか を確認

### [1] で止まる ─ port0/port1 が $AA/$BB にならない

モジュールが起動していない。表示された値で原因が切り分けられる。

読めた値 | 疑う所
$FF | モジュールが応答していない。VCC(18)とVS(24)の両方に5Vが来ているか / GND(19,23)がArduinoと共通か / /CS(1)=GND・CS(2)=+5V か / /RESET(15)がA4に繋がっているか
$00 | データバスがGNDに落ちている。D0-D7(pin 7〜14)の配線を確認
毎回違う値 | /RD(A3) か /WR(A2) の配線ミス、または結線が浮いている

### [2] で止まる ─ 1ブロック目の転送に失敗

リセットは通るのに書き込みが通らない。D0-D7 のどれかが入れ替わっているか浮いている。A0(pin3)/A1(pin4) の配線も確認する。

### [3] で止まる ─ 2ブロック目の転送に失敗

1ブロック目は通るのに2ブロック目で落ちる = ブロック切り替えのタイミング問題。配線自体は概ね正しい。ジャンパ線を短くする、電源にパスコン(0.1µF)を追加する。

### [5] でマーカーが $99 にならない

転送は通ったがジャンプが失敗している。

### よくある落とし穴

| VS(pin24)の繋ぎ忘れ — VCCだけ繋いで動かない例が最も多い
| GNDが共通でない — 外部電源を併用する場合は必ずArduinoのGNDと繋ぐ
| ジャンパ線が長い — 20cm級を使うとバスが不安定になる。10cm以下にする
| 音声出力の直結 — DCオフセットでスピーカーを傷める。必ずコンデンサを挟む
| D0-D7の順序間違い — D2→pin7 から始まる。D0→pin7 ではない

SHVC-SOUND スタンドアロンプレイヤー ／ 詳細は docs/minimal-bringup.md

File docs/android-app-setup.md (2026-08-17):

# Androidアプリ開発環境の構築(初めての人向け)

SHVC-SOUNDをスマホ単体(USB直結・PC不要)で鳴らすためのAndroidアプリを作ります。
Androidアプリ開発が初めての前提で、環境構築から順番に進めます。

**全体の流れ**
1. Android Studio(開発ツール)をインストールする
2. スマホ側で開発者向け設定を有効にする
3. 空っぽの「Hello World」アプリを実際にスマホで動かしてみる(ここが一番大事な関門)
4. SHVC-SOUND用のコードを組み込む(次のステップ、この文書では扱わない)

3番まで終われば「道具が揃って動く」ことが確認できたことになるので、
そこから先(4番)は別途コードを渡します。

---

## 1. Android Studioのインストール

1. 公式サイトを開く: https://developer.android.com/studio
2. 「Download Android Studio」をクリックし、利用規約に同意してダウンロード
3. ダウンロードした `.exe` を実行し、インストーラの指示に従う
   - 途中の「Install Type」は **Standard** を選ぶ(初期設定のままでOK)
   - SDKコンポーネントのダウンロードが走る(数GB、Wi-Fi推奨、10〜30分程度かかることがある)
4. 初回起動時のセットアップウィザードもそのまま進めて完了させる

**ここで詰まったら**: 途中でHAXM(仮想化支援)のインストールに失敗しても無視してよい。
今回はスマホ実機で動かすのでエミュレータは使わない。

---

## 2. スマホ側の準備(Android)

### 開発者向けオプションを有効にする

1. 設定 → 端末情報(「デバイス情報」等、機種により名称が違う)
2. 「ビルド番号」を**7回連続でタップ**する(「これでデベロッパーになりました」的なメッセージが出る)
3. 設定に「開発者向けオプション」という項目が新しく出現する

### USBデバッグを有効にする

1. 設定 → 開発者向けオプション
2. 「USBデバッグ」をONにする

この設定は、**開発中にPCからアプリを書き込むため**に必要。
(SHVC-SOUND本番運用時はArduinoと直結するので、この設定がなくても
アプリ自体は動くが、開発・更新のたびに毎回必要になるのでONのままでよい)

### 動作確認: PCとスマホをUSBケーブルで繋ぐ

1. 普段使っているUSBケーブルでスマホとPCを繋ぐ
2. スマホ側に「USBデバッグを許可しますか」のようなポップアップが出たら **許可**
3. 「ファイル転送」ではなく特に何も選ばなくてよい(デバッグ用の接続は自動で確立される)

---

## 3. Hello Worldアプリを実機で動かす

ここまでで道具が揃っているか、実際に確認する。

1. Android Studioを起動
2. 「New Project」→ **Empty Views Activity** を選ぶ
   (「Empty Activity」ではなく「Empty **Views** Activity」。Compose版ではない方)
3. 設定:
   - Name: `SHVCSoundPlayer` (何でもよい)
   - Package name: `com.shvcsound.player` (後で渡すコードとパッケージ名を合わせるため、これを推奨)
   - Language: **Kotlin**
   - Minimum SDK: **API 26 (Android 8.0)**
4. 「Finish」を押すとプロジェクトが作られ、裏でGradleの同期(依存関係のダウンロード)が走る
   - 画面下部に進捗バーが出る。初回は数分かかることがある。**エラーが出ずに終わるまで待つ**
5. 上部ツールバーの緑色の▶(Run)ボタンを押す
6. デバイス選択のダイアログが出たら、USBで繋いだスマホを選ぶ
   - もしスマホが一覧に出ない場合: USBケーブルを挿し直す/別のケーブルを試す
     (充電専用ケーブルだとデータ通信できないことがある)
7. スマホの画面に「Hello World!」と表示されたアプリが実際に起動すれば成功

**この時点で「Android Studio → 実機へのビルド・転送」という土台ができています。**
ここまでできたら教えてください。次にSHVC-SOUND再生用のコード一式を渡します。

---

## この後の見通し(次のステップで渡すもの)

- USBシリアル通信ライブラリ(`usb-serial-for-android`)の追加設定
- `.spc`ファイルを解析するコード(Pythonの`spc_play.py`と同じロジック)
- Arduinoへ転送するコード(`spc_uploader.ino`と全く同じ通信手順。ファームウェア側は変更不要)
- 簡単な画面(曲一覧・再生ボタン・音量スライダー)

Arduino側のファームウェアは既に実機で動作確認済みのものをそのまま使うので、
アプリ側さえ正しく動けば、PCなしでスマホ単体での再生が動く見込みです。

ただし、**このAndroidアプリのコードはこの開発環境(Windows・Android SDK無し)では
実際にビルド・実行して確認することができません。** 渡すコードは書けますが、
最終的に動くかどうかはあなたのAndroid Studio環境で確認してもらうことになります。

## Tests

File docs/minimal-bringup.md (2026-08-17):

# 最小構成での実機立ち上げ手順

音が出ない原因を切り分けるための、**アンプと12V系を一切使わない**最小構成。
必要なのは Arduino Uno R3(またはNano)、SHVC-SOUNDモジュール、ジャンパ線、電解コンデンサ1個、アンプ付きスピーカーだけ。

TDA7053A・12V PDトリガー・音量制御・3.5mmジャックは**全部外す**。
これらは「音が出ない」原因になり得る要素なので、まず疑いの対象から消す。
基板が既にできている場合は、TDA7053AをICソケットから抜き、12V電源を繋がずに、
モジュールの音声ピンから直接引き出す。

> **印刷用**: この配線表はA4 2ページのPDFにしてある → [`SHVC-SOUND_配線表_A4.pdf`](SHVC-SOUND_配線表_A4.pdf)
> チェックボックス付きなので、配線しながら1本ずつ潰していける。
> 再生成は `wiring-sheet.html` を編集して以下を実行:
>
> ```
> chrome --headless=new --no-pdf-header-footer --print-to-pdf=docs/SHVC-SOUND_配線表_A4.pdf file:///.../docs/wiring-sheet.html
> ```

## 配線より先に: 1番ピンを確定させる

**24pinコネクタは2列×12・2mmピッチで、キー(切り欠き)が無い。**
逆向きにも物理的に挿さり、その場合 pin24(VS/+5V)の位置に pin1(/CS)が来て
電源とGNDが入れ替わりモジュールを壊す。ベンダー提供のフットプリント
(`Conn_SHVC-SOUND_Male.kicad_mod`)を確認したが、パッドは24個すべて丸で
1番角パッドの慣例が無く、キー溝も無い。**シルクの数字以外に物理的な手がかりが無い。**

代わりに、テスターの導通モードだけで確実に判別できる。**電源は入れないこと。**

1. テスターを導通(ブザー)モードにし、片方のプローブをモジュールの金属シールド、
   または基板の大きなベタ面に当てて固定する
2. もう片方で24本すべてを順に当たり、導通するピンを全部書き出す
3. 導通するのは **pin19 と pin23 の2本だけ**

この2本の並びが決定的な手がかりになる:

```
奇数列  [23]GND  [21]Audio-L  [19]GND   17   15  …   3    1     ← pin1/2側
偶数列  [24]      [22]         [20]      18   16  …   4    2
        ↑この端が23/24側                      ↑この側には導通するピンは1本も無い
```

- 導通する2本は**同じ列**にあり、**間に1本挟んで**並び、**片方がコネクタの端**にある
- 端にある方が **pin23**、間の1本が **pin21(Audio-L)**、もう片方が **pin19**
- → **その列が奇数列**、**その端が23/24側**、**反対の端が pin1/2 で pin1 は GND と同じ列**

GNDの並びは片側にしか現れないので、これで向きが一意に決まる。
pin1(/CS)は入力ピンでモジュール内部ではGNDに落ちていないため、誤検出にはならない。

**導通するピンが3本以上ある場合はここで止める。** 基準にしたベタ面がGNDでない可能性がある。

向きが確定したら、油性ペンでモジュールのpin1側に印を付けておく。

## 配線一覧(全17本)

### 電源(4本)

| Arduino | SHVC-SOUND pin | 備考 |
|---|---|---|
| 5V | 18 (VCC) | |
| 5V | 24 (VS) | **忘れやすい。ここが浮いていると全く動かない** |
| GND | 19 (GND) | |
| GND | 23 (GND) | |

USBから給電する。モジュールの消費は100〜200mA程度なのでUSBの500mAで足りる。

### 固定ピン(3本)

| 接続先 | SHVC-SOUND pin | 信号 |
|---|---|---|
| GND | 1 | /CS |
| +5V | 2 | CS |
| +5V | 20 | /MUTE(D10を使わず+5V直結でよい) |

pin 16 (NC) と pin 17 (DCK) は**未接続のまま**。

### バス(13本)

| Arduino | SHVC-SOUND pin | 信号 |
|---|---|---|
| D2 | 7 | D0 |
| D3 | 8 | D1 |
| D4 | 9 | D2 |
| D5 | 10 | D3 |
| D6 | 11 | D4 |
| D7 | 12 | D5 |
| D8 | 13 | D6 |
| D9 | 14 | D7 |
| A0 | 3 | A0 |
| A1 | 4 | A1 |
| A2 | 5 | /WR |
| A3 | 6 | /RD |
| A4 | 15 | /RESET |

### 音声出力(最小: モノラルで2本)

```
SHVC-SOUND pin21 (Audio-L) --[+ 10µF電解 -]-- アンプ付きスピーカーの入力(L)
共通GND                     ------------------ アンプ付きスピーカーのGND
```

- コンデンサの**+側をモジュール側**に向ける(出力にDCオフセットが乗っているため直結しない)
- 容量は10µF〜100µFなら何でもよい
- ステレオで聴きたければ pin22 (Audio-R) にも同様にもう1本
- **イヤホン直挿しは避ける**。アンプ付きPCスピーカーか、オーディオIFのライン入力を使う

## 手順

1. 上記の通り配線する(12Vは絶対に繋がない)
2. `SHVC-SOUND_python/hw_selftest/hw_selftest.ino` を書き込む
3. Arduino IDE のシリアルモニタを **115200bps** で開く
4. 自動でテストが走る。何かキーを送ると再実行

## 結果の読み方

### 全部 [OK] でノイズが鳴る
ハードは完動。音が出ない原因は `spc_play.py` 側にある。

### 全部 [OK] なのに無音
転送も実行も成功しているので、**原因は音声出力側だけ**に絞れる。
コンデンサの極性、スピーカー側の音量、/MUTE(pin20)がHIGHか、を確認する。

### [1] で止まる(port0/port1 が $AA/$BB にならない)
モジュールが起動していない。読めた値で原因が分かる:

| 読めた値 | 疑う所 |
|---|---|
| `$FF` | モジュールが応答していない。VCC(18)とVS(24)**両方**に5Vが来ているか、GND(19,23)が共通か、/CS(1)=GND・CS(2)=+5V か、/RESET(15)がA4に繋がっているか |
| `$00` | データバスがGNDに落ちている。D0-D7(7〜14番)の配線を確認 |
| 毎回違う値 | /RD(A3)か/WR(A2)の配線ミス、または結線が浮いている |

### [2] で止まる
リセットは通るがデータの書き込みが通らない。D0-D7 のどれかが入れ替わっているか浮いている。
A0(3)/A1(4) の配線も確認する。

### [3] で止まる
1ブロック目は通るのに2ブロック目で落ちる = ブロック切り替えのタイミング問題。
配線は概ね正しいので、ジャンパ線を短くする・電源のパスコンを追加する。

### [5] でマーカーが $99 にならない
転送は通ったがジャンプが失敗している。

## よくある落とし穴

- **VS(24番)の繋ぎ忘れ** — VCCだけ繋いで動かない例が多い
- **GNDが共通でない** — ボードと外部電源を併用する場合は必ずGNDを繋ぐ
- **ジャンパ線が長い** — ブレッドボードで20cm級の線を使うとバスが不安定になる。10cm以下に
- **音声出力の直結** — DCオフセットでスピーカーを傷める。必ずコンデンサを挟む

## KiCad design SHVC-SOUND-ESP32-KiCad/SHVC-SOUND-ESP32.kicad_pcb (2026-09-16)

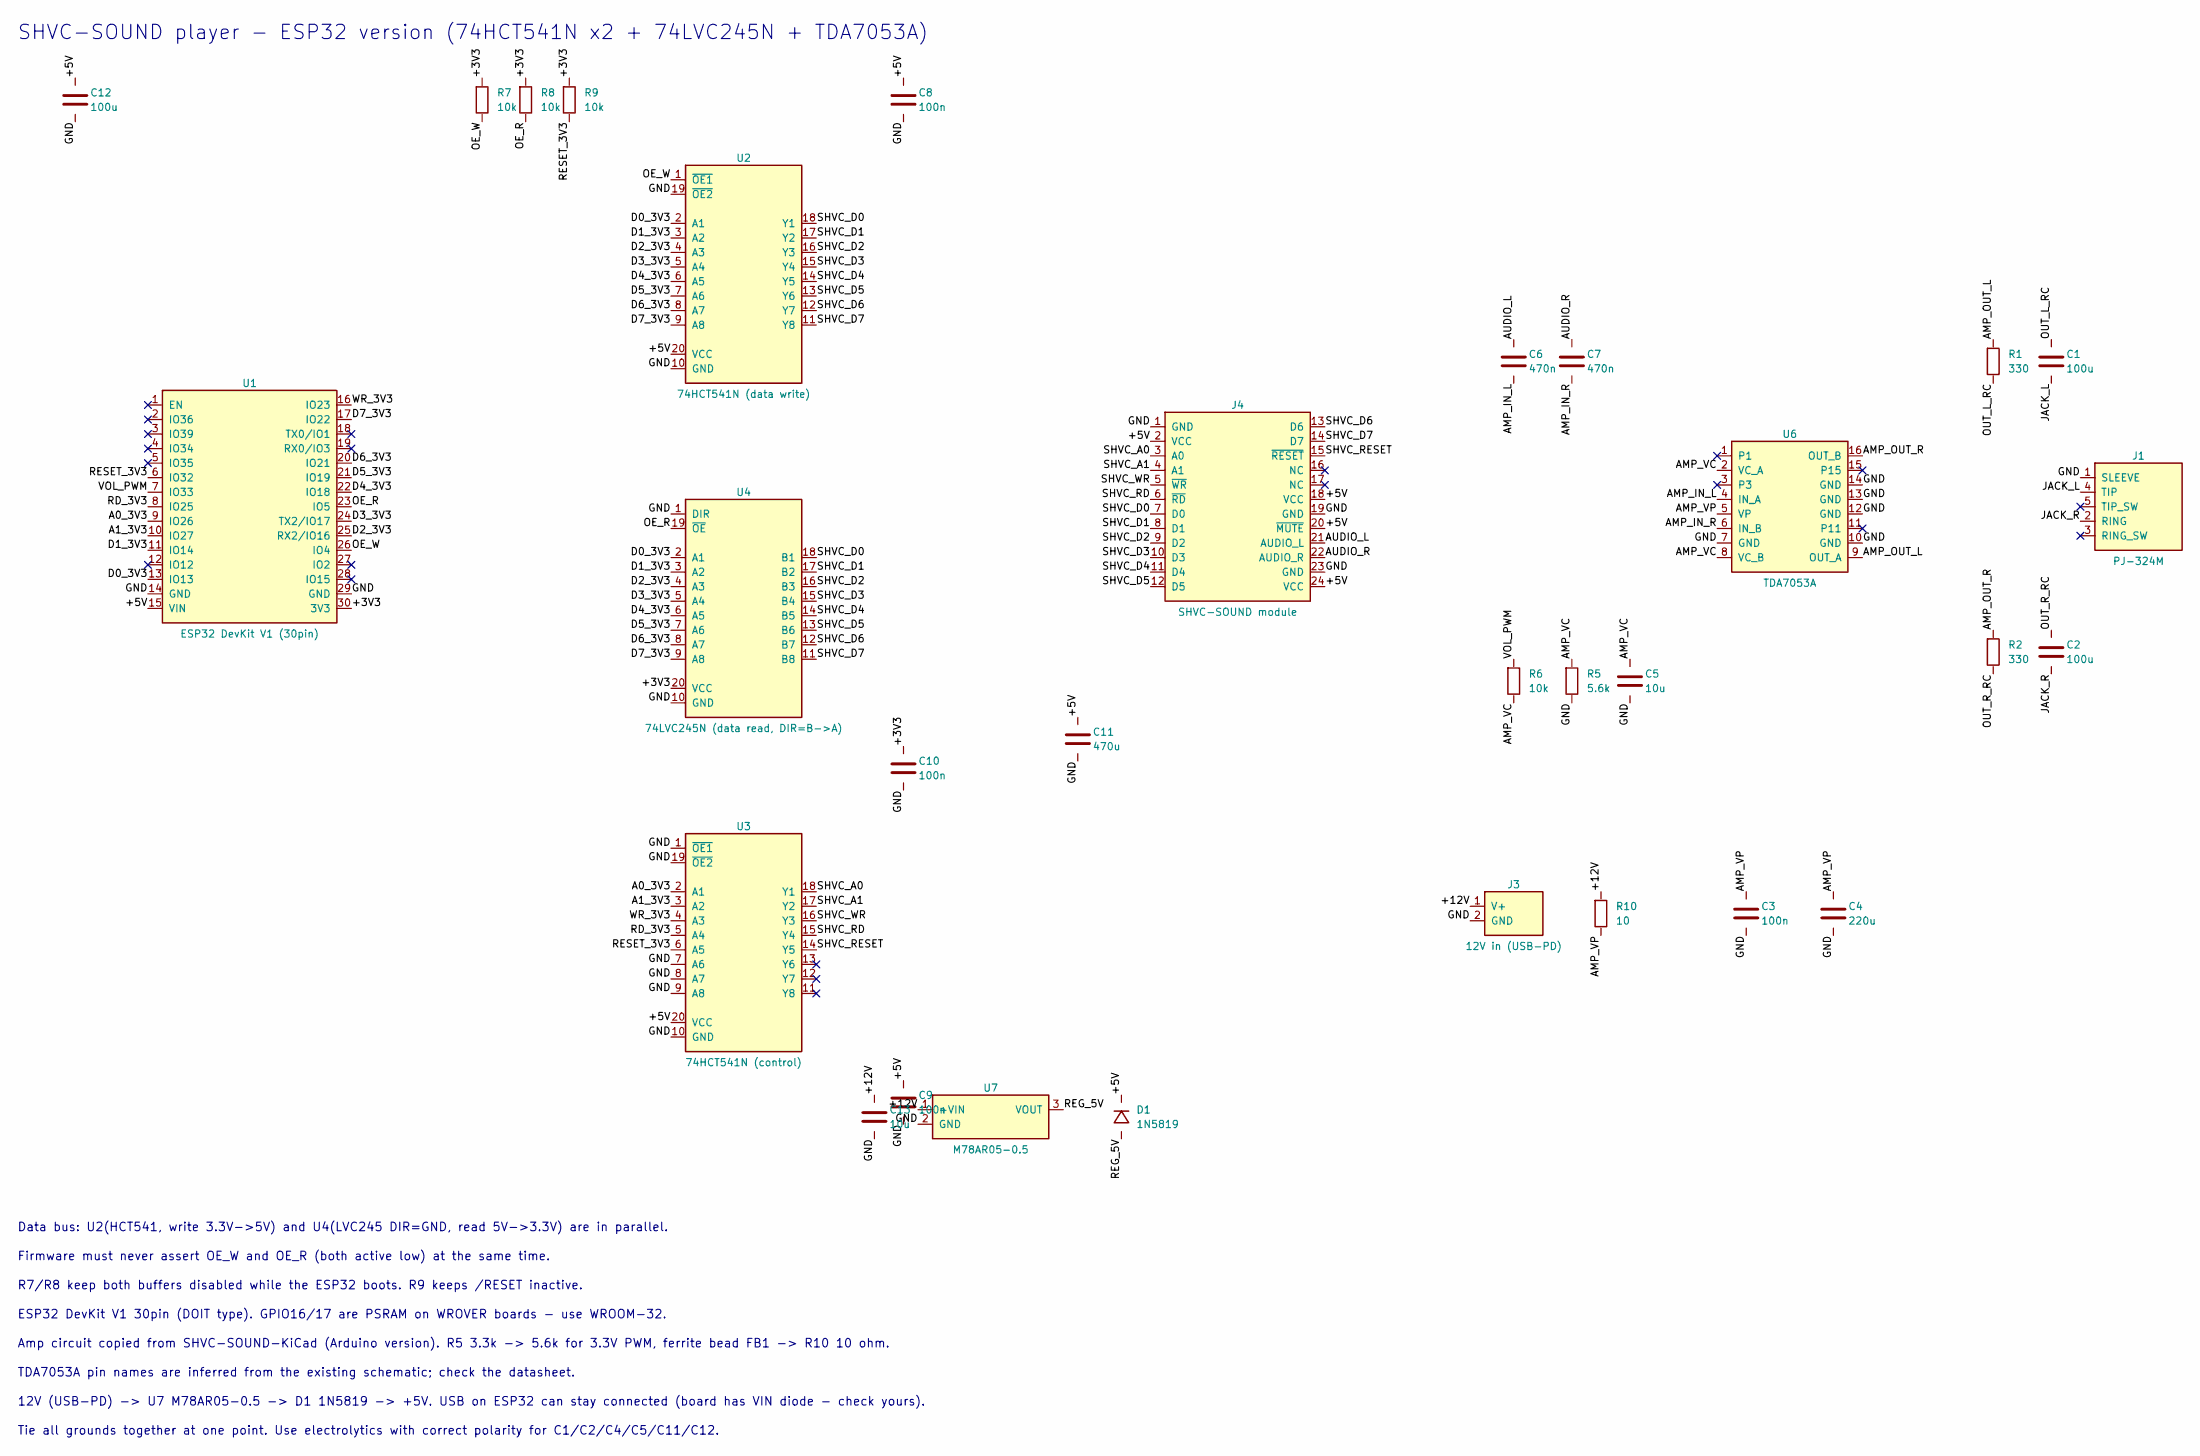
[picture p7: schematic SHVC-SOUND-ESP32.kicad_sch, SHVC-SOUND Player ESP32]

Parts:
C1, C2, C12: 100u; CP_Radial_D6.3mm_P2.50mm
C3, C8, C9, C10: 100n; C_Disc_D3.0mm_W1.6mm_P2.50mm
C4: 220u; CP_Radial_D8.0mm_P3.50mm
C5, C13: 10u; CP_Radial_D5.0mm_P2.00mm
C6, C7: 470n; C_Disc_D5.0mm_W2.5mm_P5.00mm
C11: 470u; CP_Radial_D10.0mm_P5.00mm
D1: 1N5819; D_DO-41_SOD81_P7.62mm_Horizontal
J1: PJ-324M
J3: 12V in (USB-PD); PD_INPUT_MODULE_2P
J4: SHVC-SOUND module; SHVC-SOUND-MB
R1, R2: 330; R_Axial_DIN0207_L6.3mm_D2.5mm_P7.62mm_Horizontal
R5: 5.6k; R_Axial_DIN0207_L6.3mm_D2.5mm_P7.62mm_Horizontal
R6, R7, R8, R9: 10k; R_Axial_DIN0207_L6.3mm_D2.5mm_P7.62mm_Horizontal
R10: 10; R_Axial_DIN0207_L6.3mm_D2.5mm_P7.62mm_Horizontal
U1: ESP32 DevKit V1 (30pin); ESP32-DevKit-30_Socket
U2: 74HCT541N (data write); DIP-20_W7.62mm
U3: 74HCT541N (control); DIP-20_W7.62mm
U4: 74LVC245N (data read, DIR=B->A); DIP-20_W7.62mm
U6: TDA7053A; DIP-16_W7.62mm
U7: M78AR05-0.5; DCDC_SIP3_7805

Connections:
+3V3: C10.1 (K), R7.1 (K), R8.1 (K), R9.1 (K), U1.30 (3V3), U4.20 (VCC)
+5V: C8.1 (K), C9.1 (K), C11.1 (K), C12.1 (K), D1.1 (K), J4.2 (VCC), J4.18 (VCC), J4.20 (~MUTE), J4.24 (VCC), U1.15 (VIN), U2.20 (VCC), U3.20 (VCC)
+12V: C13.1 (K), J3.1 (V+), R10.1 (K), U7.1 (+VIN)
A0_3V3: U1.9 (IO26), U3.2 (A1)
A1_3V3: U1.10 (IO27), U3.3 (A2)
AMP_IN_L: C6.2 (A), U6.4 (IN_A)
AMP_IN_R: C7.2 (A), U6.6 (IN_B)
AMP_OUT_L: R1.1 (K), U6.9 (OUT_A)
AMP_OUT_R: R2.1 (K), U6.16 (OUT_B)
AMP_VC: C5.1 (K), R5.1 (K), R6.2 (A), U6.2 (VC_A), U6.8 (VC_B)
AMP_VP: C3.1 (K), C4.1 (K), R10.2 (A), U6.5 (VP)
AUDIO_L: C6.1 (K), J4.21 (AUDIO_L)
AUDIO_R: C7.1 (K), J4.22 (AUDIO_R)
D0_3V3: U1.13 (IO13), U2.2 (A1), U4.2 (A1)
D1_3V3: U1.11 (IO14), U2.3 (A2), U4.3 (A2)
D2_3V3: U1.25 (RX2/IO16), U2.4 (A3), U4.4 (A3)
D3_3V3: U1.24 (TX2/IO17), U2.5 (A4), U4.5 (A4)
D4_3V3: U1.22 (IO18), U2.6 (A5), U4.6 (A5)
D5_3V3: U1.21 (IO19), U2.7 (A6), U4.7 (A6)
D6_3V3: U1.20 (IO21), U2.8 (A7), U4.8 (A7)
D7_3V3: U1.17 (IO22), U2.9 (A8), U4.9 (A8)
GND: C3.2 (A), C4.2 (A), C5.2 (A), C8.2 (A), C9.2 (A), C10.2 (A), C11.2 (A), C12.2 (A), C13.2 (A), J1.1 (SLEEVE), J3.2 (GND), J4.1 (GND), J4.19 (GND), J4.23 (GND), R5.2 (A), U1.14 (GND), U1.29 (GND), U2.10 (GND), U2.19 (~OE2), U3.1 (~OE1), U3.7 (A6), U3.8 (A7), U3.9 (A8), U3.10 (GND), U3.19 (~OE2), U4.1 (DIR), U4.10 (GND), U6.7 (GND), U6.10 (GND), U6.12 (GND), U6.13 (GND), U6.14 (GND), U7.2 (GND)
JACK_L: C1.2 (A), J1.4 (TIP)
JACK_R: C2.2 (A), J1.2 (RING)
OE_R: R8.2 (A), U1.23 (IO5), U4.19 (~OE)
OE_W: R7.2 (A), U1.26 (IO4), U2.1 (~OE1)
OUT_L_RC: C1.1 (K), R1.2 (A)
OUT_R_RC: C2.1 (K), R2.2 (A)
RD_3V3: U1.8 (IO25), U3.5 (A4)
REG_5V: D1.2 (A), U7.3 (VOUT)
RESET_3V3: R9.2 (A), U1.6 (IO32), U3.6 (A5)
SHVC_A0: J4.3 (A0), U3.18 (Y1)
SHVC_A1: J4.4 (A1), U3.17 (Y2)
SHVC_D0: J4.7 (D0), U2.18 (Y1), U4.18 (B1)
SHVC_D1: J4.8 (D1), U2.17 (Y2), U4.17 (B2)
SHVC_D2: J4.9 (D2), U2.16 (Y3), U4.16 (B3)
SHVC_D3: J4.10 (D3), U2.15 (Y4), U4.15 (B4)
SHVC_D4: J4.11 (D4), U2.14 (Y5), U4.14 (B5)
SHVC_D5: J4.12 (D5), U2.13 (Y6), U4.13 (B6)
SHVC_D6: J4.13 (D6), U2.12 (Y7), U4.12 (B7)
SHVC_D7: J4.14 (D7), U2.11 (Y8), U4.11 (B8)
SHVC_RD: J4.6 (~RD), U3.15 (Y4)
SHVC_RESET: J4.15 (~RESET), U3.14 (Y5)
SHVC_WR: J4.5 (~WR), U3.16 (Y3)
VOL_PWM: R6.1 (K), U1.7 (IO33)
WR_3V3: U1.16 (IO23), U3.4 (A3)

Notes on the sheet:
SHVC-SOUND player - ESP32 version (74HCT541N x2 + 74LVC245N + TDA7053A)
Data bus: U2(HCT541, write 3.3V->5V) and U4(LVC245 DIR=GND, read 5V->3.3V) are in parallel.
Firmware must never assert OE_W and OE_R (both active low) at the same time.
R7/R8 keep both buffers disabled while the ESP32 boots. R9 keeps /RESET inactive.
ESP32 DevKit V1 30pin (DOIT type). GPIO16/17 are PSRAM on WROVER boards - use WROOM-32.
Amp circuit copied from SHVC-SOUND-KiCad (Arduino version). R5 3.3k -> 5.6k for 3.3V PWM, ferrite bead FB1 -> R10 10 ohm.
TDA7053A pin names are inferred from the existing schematic; check the datasheet.
12V (USB-PD) -> U7 M78AR05-0.5 -> D1 1N5819 -> +5V. USB on ESP32 can stay connected (board has VIN diode - check yours).
Tie all grounds together at one point. Use electrolytics with correct polarity for C1/C2/C4/C5/C11/C12.

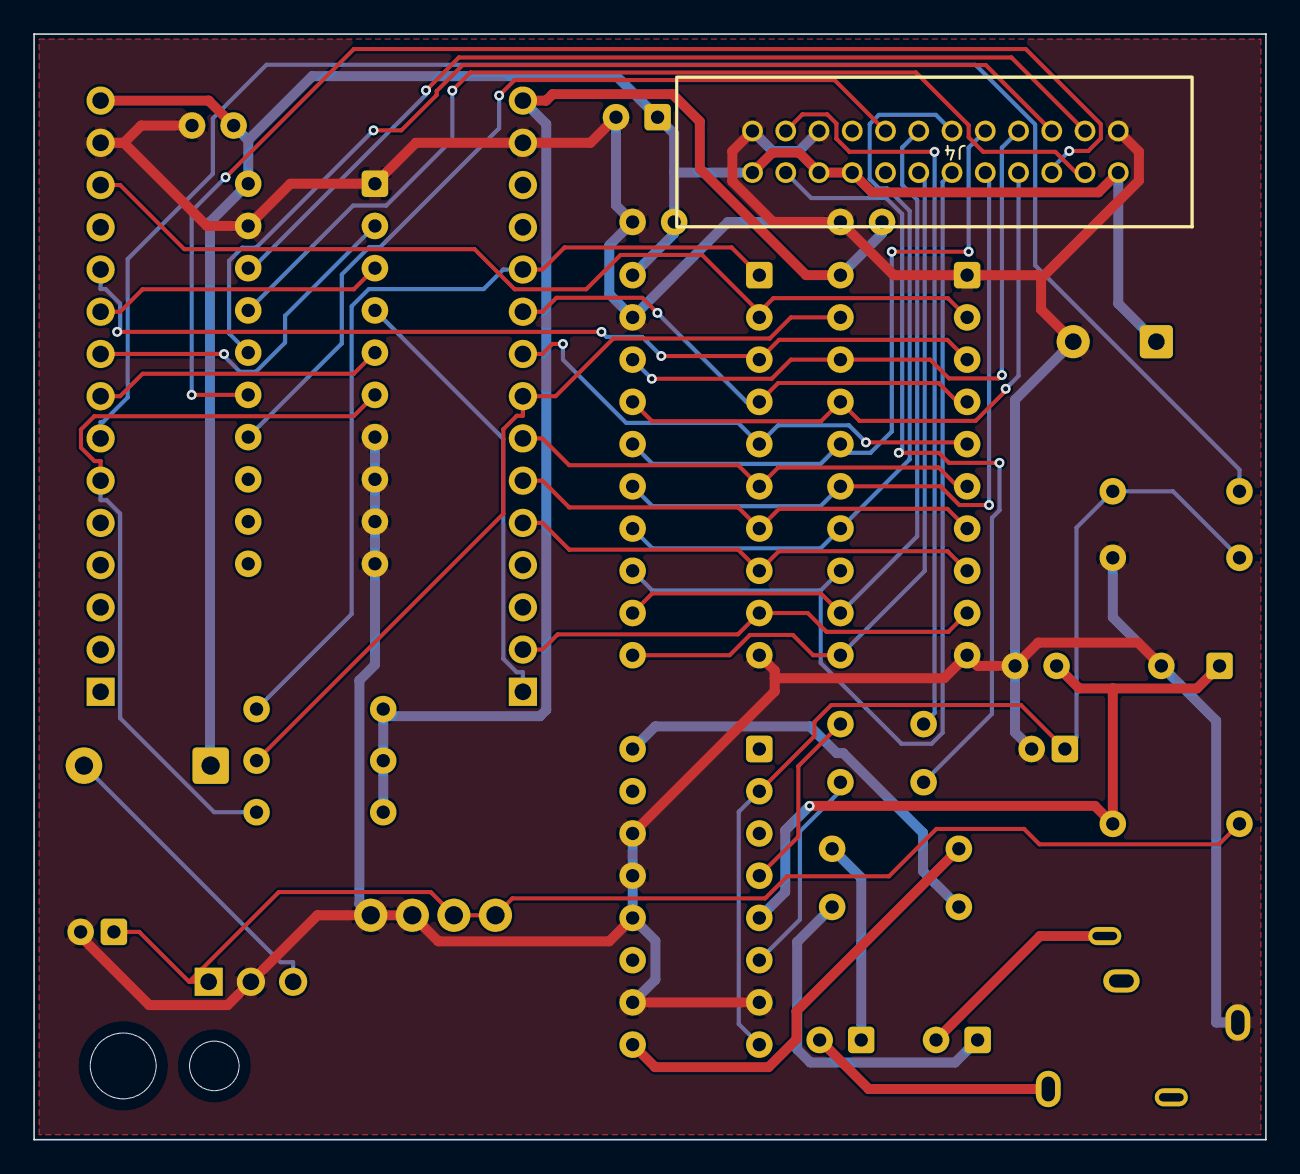
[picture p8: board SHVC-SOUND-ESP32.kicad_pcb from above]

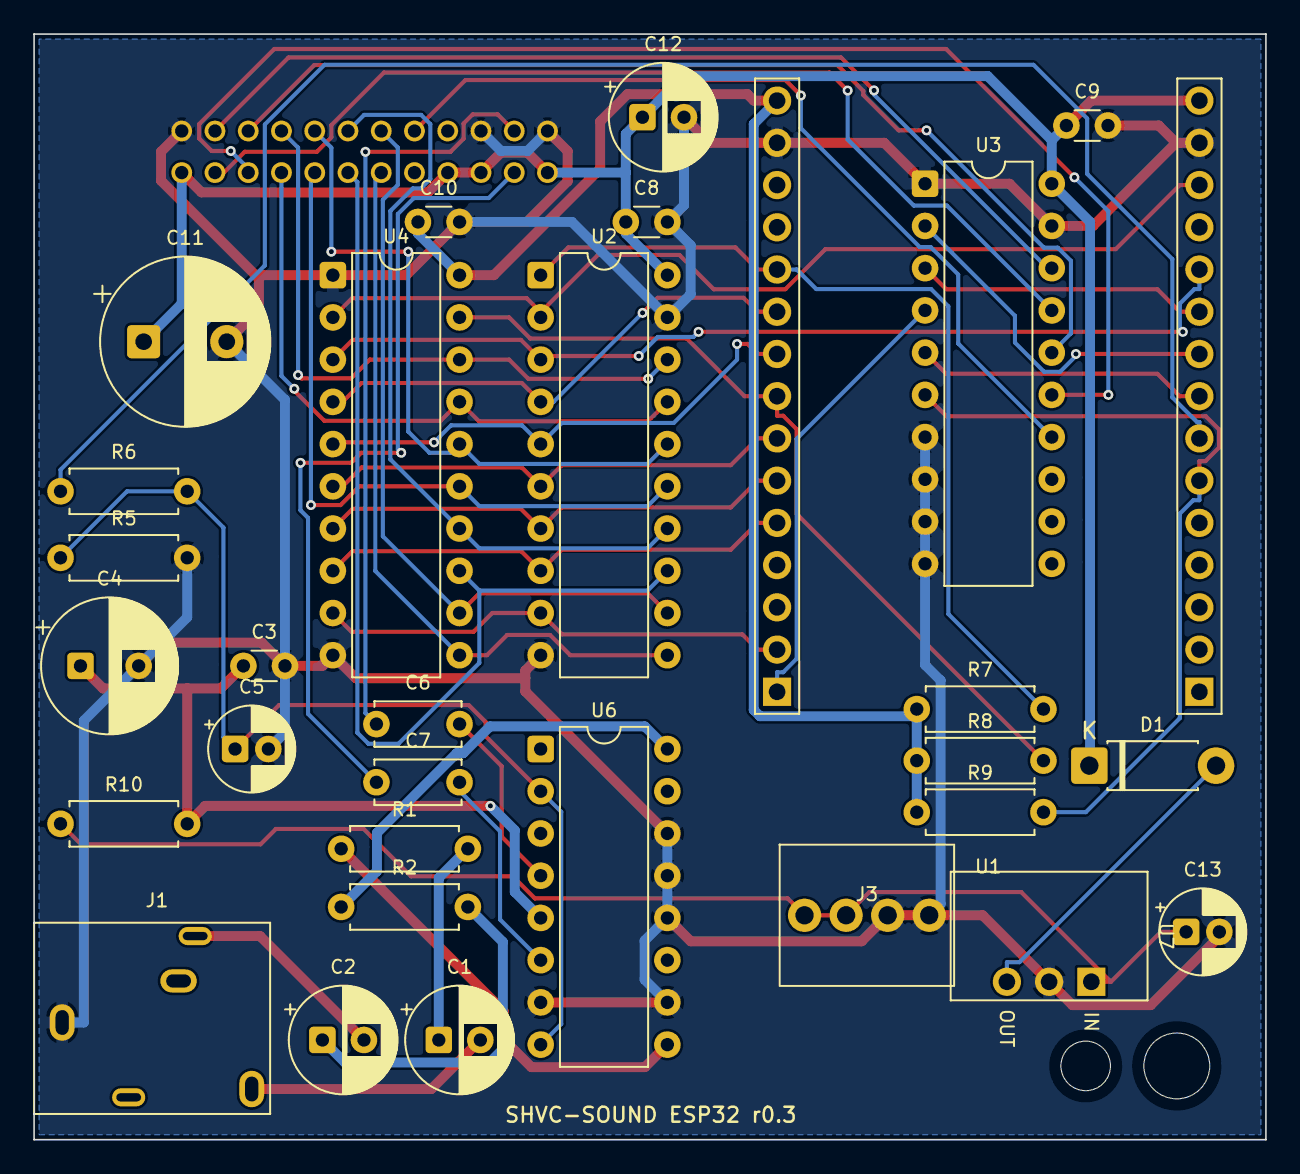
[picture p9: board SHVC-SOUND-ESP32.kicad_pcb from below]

Board: 2 copper layers, 74.1 x 66.5 mm, 33 parts (30 on the bottom side), 46 nets.

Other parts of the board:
H1: hole 3.96mm; NPTH_Hole_3.96mm
H2: hole 2.98mm; NPTH_Hole_2.98mm

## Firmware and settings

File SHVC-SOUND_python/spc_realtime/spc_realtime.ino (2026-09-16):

/*
 * spc_realtime.ino - SHVC-SOUND リアルタイム演奏対応ファームウェア (Arduino Uno R3 / Nano)
 *
 * spc_uploader.ino の上位互換。従来の .spc 転送コマンド(CMD_RESET/SETADDR/
 * SENDBYTES/READPORT/SETVOLUME)はそのまま残してあるので、spc_gui.py /
 * spc_play.py はこのファームでも今までどおり動く。
 *
 * 追加したのはMIDIリアルタイム演奏(midi2spc/hardware.py)用の3コマンド:
 *
 *   CMD_DSPWRITE (0x07) [reg][val]
 *       SPC700側の常駐ドライバ経由でDSPレジスタを1個書く。
 *
 *   CMD_STREAM (0x08)
 *       以後、4バイトのイベントレコードを連続で受け取る。
 *         [待ち時間LE16 (100µs単位)][DSPレジスタ番号][値]
 *       レコードはリングバッファに積まれ、指定の時刻どおりに実行される。
 *       レジスタ番号 0xFF は「DSPには書かず待つだけ」のNOP。
 *       FF FF FF FF を受け取るとストリーム終了。
 *       1レコード消化するごとにクレジットバイト(0x5A)を返すので、
 *       PC側はそれを数えて送りすぎを防ぐ(フロー制御)。
 *
 *   CMD_PANIC (0x09)
 *       全ボイスをキーオフしてマスター音量を0にする(緊急停止)。
 *
 * ■ なぜSPC700側にドライバが必要か
 *   S-DSPのレジスタはSPC700からしか触れない。ホスト(Arduino)から見えるのは
 *   $F4-$F7の4バイトの窓だけ。そこで「$F5のレジスタ番号と$F6の値をDSPへ
 *   書き写すだけ」の23バイトの常駐ループをSPC700に置き、Arduinoはその窓越しに
 *   指示を出す。曲の解釈はすべてPC側に残るので、SPC700側はこれで足りる。
 *   ドライバ本体は midi2spc/hardware.py の DRIVER_CODE にある。
 *
 * ピン配置は spc_uploader.ino と同一(PROJECT_BRIEF.md 3.1節)。
 */

const uint8_t DATA_PINS[8] = {2, 3, 4, 5, 6, 7, 8, 9};
const uint8_t ARD_A0 = A0;
const uint8_t ARD_A1 = A1;
const uint8_t PIN_WR = A2;
const uint8_t PIN_RD = A3;
const uint8_t PIN_RESET = A4;
const uint8_t PIN_VOLUME = 10;

// シリアルコマンド (PC -> Arduino)
const uint8_t CMD_RESET = 0x01;
const uint8_t CMD_SETADDR = 0x02;
const uint8_t CMD_SENDBYTES = 0x03;
const uint8_t CMD_READPORT = 0x04;
const uint8_t CMD_SETVOLUME = 0x05;
const uint8_t CMD_DSPWRITE = 0x07;
const uint8_t CMD_STREAM = 0x08;
const uint8_t CMD_PANIC = 0x09;
const uint8_t CMD_PING = 0x0A;
const uint8_t CMD_WRITEPORT = 0x0B;   // 2バイト引数(ポート番号, 値)。SPC再生開始時に曲の入力ポート値を置く
const uint8_t CMD_PCMCHUNK = 0x0C;    // 1バイト長さN + Nバイト。PCMストリーミング用ドライバのリングバッファへ書く
const uint8_t CMD_DRVQUERY = 0x0D;    // 3バイト(ドライバのコマンド, 引数1, 引数2)。応答は [0x0D, $F5, $F6]
const uint8_t CMD_DRVPEEK = 0x0E;     // 1バイト長さN。ドライバの読み返し(6)をN回行い、[0x0E, Nバイト]を返す
const uint8_t CMD_PCMBULK = 0x0F;     // 1バイト長さN(3の倍数) + Nバイト。ドライバの一括受信モード(7)で3バイトずつ書く
const uint8_t CMD_BULKTIMING = 0x10;  // 3バイト(セットアップµs, ストローブµs, ホールドµs)。一括送信の待ち時間を変える
const uint8_t CMD_SETBAUD = 0x11;     // 1バイト(0=500k, 1=1M, 2=2M)。旧速度で応答してから切り替える。リセットで500kに戻る
const uint8_t CMD_BULKSTATS = 0x12;   // 応答 [0x12, 受信µs(LE32), バスµs(LE32), 待ちポーリング回数(LE32)] を返してゼロに戻す

// PING応答。PC側はこれでファームの種類とバージョンを確認する。
// 旧 spc_uploader.ino は未知のコマンドを黙って捨てるため、
// PINGに無反応 = 旧ファームが載っている、と判別できる。
const uint8_t PING_MAGIC = 0xA5;
const uint8_t FIRMWARE_VERSION = 1;

// シリアル応答 (Arduino -> PC)
const uint8_t ACK_RESET = 0x01;
const uint8_t ACK_SETADDR = 0x02;
const uint8_t ACK_SENDBYTES = 0x03;
const uint8_t ACK_DSPWRITE = 0x07;
const uint8_t ACK_STREAM_DONE = 0x08;
const uint8_t ACK_PANIC = 0x09;
const uint8_t ACK_WRITEPORT = 0x0B;
const uint8_t ACK_PCMCHUNK = 0x0C;
const uint8_t MARKER_BYTE_OK = 0xCD;
const uint8_t MARKER_TIMEOUT = 0xEE;
const uint8_t CREDIT_BYTE = 0x5A;
const uint8_t ERR_DRIVER_TIMEOUT = 0xE7;

uint8_t transferIndex = 0;
bool firstBlock = true;
uint8_t driverSeq = 0;   // 常駐ドライバとのハンドシェイク用シーケンス値

// ==================== 高速バスI/O(AVRポートレジスタ直叩き) ====================
// 詳細は spc_uploader.ino のコメント参照。1バイトあたりの処理を
// ポート書き込み数回まで削るための直接操作。

const uint8_t DATA_LOW_MASK = 0b11111100;   // PORTD bit2-7 (D2-D7)
const uint8_t DATA_HIGH_MASK = 0b00000011;  // PORTB bit0-1 (D8-D9)

void setDataBusOutput() {
  DDRD |= DATA_LOW_MASK;
  DDRB |= DATA_HIGH_MASK;
}

void setDataBusInput() {
  DDRD &= ~DATA_LOW_MASK;
  DDRB &= ~DATA_HIGH_MASK;
}

inline void busWriteData(uint8_t v) {
  PORTD = (PORTD & ~DATA_LOW_MASK) | ((v << 2) & DATA_LOW_MASK);
  PORTB = (PORTB & ~DATA_HIGH_MASK) | ((v >> 6) & DATA_HIGH_MASK);
}

inline uint8_t busReadData() {
  uint8_t low = (PIND & DATA_LOW_MASK) >> 2;
  uint8_t high = (PINB & DATA_HIGH_MASK) << 6;
  return low | high;
}

inline void selectAddr(uint8_t port) {
  PORTC = (PORTC & ~0b00000011) | (port & 0b00000011);
}

// 書き込みだけの転送(BRRサンプル・常駐ドライバ等)は3µsのままでも
// 何度やっても化けたことがない。化けるのはSPC700からの読み戻し
// (port0の応答確認)だけなので、そちらだけ余裕を持たせる。
// 2026-09-13: 両方とも15µsにしたところ、密なストリーム再生(和音が
// 集中する曲)で処理が追いつかずテンポが遅れて聞こえたため、
// 書き込みは元の速さに戻し、読み取りだけ延長する形にした。
const uint8_t WRITE_DELAY_US = 3;
const uint8_t READ_DELAY_US = 15;

void writePort(uint8_t port, uint8_t val) {
  setDataBusOutput();
  selectAddr(port);
  busWriteData(val);
  delayMicroseconds(WRITE_DELAY_US);
  PORTC &= ~(1 << 2);
  delayMicroseconds(WRITE_DELAY_US);
  PORTC |= (1 << 2);
  delayMicroseconds(WRITE_DELAY_US);
}

uint8_t readPort(uint8_t port) {
  setDataBusInput();
  selectAddr(port);
  PORTC &= ~(1 << 3);
  delayMicroseconds(READ_DELAY_US);
  uint8_t v = busReadData();
  PORTC |= (1 << 3);
  delayMicroseconds(READ_DELAY_US);
  return v;
}

bool waitForPort(uint8_t port, uint8_t expected, uint32_t timeoutMs) {
  uint32_t start = millis();
  while (millis() - start < timeoutMs) {
    if (readPort(port) == expected) return true;
  }
  return false;
}

int16_t serialReadByteBlocking(uint32_t timeoutMs) {
  uint32_t start = millis();
  while (millis() - start < timeoutMs) {
    if (Serial.available() > 0) return Serial.read();
  }
  return -1;
}

uint8_t serialReadByteForever() {
  while (Serial.available() <= 0) { /* spin */ }
  return (uint8_t)Serial.read();
}

bool readSerialExact(uint8_t *buf, uint8_t len, uint32_t timeoutMs) {
  for (uint8_t i = 0; i < len; i++) {
    int16_t b = serialReadByteBlocking(timeoutMs);
    if (b < 0) return false;
    buf[i] = (uint8_t)b;
  }
  return true;
}

// ==================== SPC700常駐ドライバとのやり取り ====================
//
// ドライバは $F4 の値が変わるのを待っている。
// $F5 にレジスタ番号、$F6 に値を置いてから $F4 に新しいシーケンス値を
// 書くと、DSPへ書き写して $F4 に同じ値を返してくる。
//
// ドライバのループは十数サイクル(約5µs)なので、待ち時間はごく短い。
// 応答が来ない = ドライバが動いていない、ということなのでタイムアウトは短くてよい。

// 接触不良で読み取りが一瞬乱れても持ちこたえられるよう、本来必要な
// 数十µsよりだいぶ余裕を持たせている(2026-09-13、長時間ストリーム再生中に
// 断続的な接触不良でドライバ応答を誤検出したため)。
const uint32_t DRIVER_TIMEOUT_MS = 100;

bool dspWrite(uint8_t reg, uint8_t val) {
  // $F7はPCMストリーミング用ドライバのコマンド欄(0=DSP書き込み)。
  // 従来の23バイトのドライバは$F7を読まないので、書いても影響しない。
  writePort(3, 0);
  writePort(1, reg);
  writePort(2, val);
  driverSeq++;
  writePort(0, driverSeq);
  return waitForPort(0, driverSeq, DRIVER_TIMEOUT_MS);
}

void handleDspWrite() {
  uint8_t buf[2];
  if (!readSerialExact(buf, 2, 3000)) return;
  if (dspWrite(buf[0], buf[1])) {
    Serial.write(ACK_DSPWRITE);
  } else {
    Serial.write(ERR_DRIVER_TIMEOUT);
  }
}

void handlePing() {
  Serial.write(PING_MAGIC);
  Serial.write(FIRMWARE_VERSION);
}

void handlePanic() {
  dspWrite(0x5C, 0xFF);  // KOF: 全ボイスをキーオフ
  dspWrite(0x5C, 0x00);
  dspWrite(0x0C, 0x00);  // MVOLL
  dspWrite(0x1C, 0x00);  // MVOLR
  Serial.write(ACK_PANIC);
}

// ==================== イベントストリーム ====================
//
// 4バイトのレコードをリングバッファに積み、待ち時間どおりに実行する。
// PC側は「クレジット」の数だけ先行して送ってよい。1レコード消化ごとに
// クレジットバイトを1つ返す。
//
// EVENT_SLOTS はPC側 hardware.py の STREAM_CREDITS より大きくしておくこと
// (PCが先行送信できる量をリングバッファが必ず受けきれるようにするため)。

// 和音のキーオンは1音あたり11レジスタ書き込みになるため、8音同時だと
// 88レコードが一気に来る。段数が少ないとそのたびPCとの往復待ちが入って
// 発音が滲むので、余裕を持たせてある(96段でRAM384バイト)。
const uint8_t EVENT_SLOTS = 96;

// リングバッファは構造体ではなく並列配列で持つ。
// Arduinoのスケッチはビルド時に関数プロトタイプが自動挿入されるが、
// その挿入位置は自作の型定義より前になるため、構造体を引数や戻り値に
// 使うと 'Event' does not name a type でコンパイルが通らない。
uint16_t ringDelay[EVENT_SLOTS];  // 直前のイベントからの待ち時間(100µs単位)
uint8_t ringReg[EVENT_SLOTS];     // DSPレジスタ番号 (0xFF = 待つだけのNOP)
uint8_t ringVal[EVENT_SLOTS];
uint8_t ringHead = 0;
uint8_t ringTail = 0;
uint8_t ringCount = 0;

// PCからの供給が途絶えたと判断するまでの時間
const uint32_t STREAM_STARVE_TIMEOUT_MS = 5000;

void handleStream() {
  ringHead = ringTail = ringCount = 0;

  bool inputDone = false;
  bool driverLost = false;
  uint32_t dueTime = micros();     // 次に実行すべきイベントの絶対時刻
  bool dueValid = false;
  uint32_t lastActivity = millis();

  while (true) {
    // --- 1. 受信: 空きがある限り4バイト単位で取り込む ---
    while (!inputDone && ringCount < EVENT_SLOTS && Serial.available() >= 4) {
      uint8_t lo = Serial.read();
      uint8_t hi = Serial.read();
      uint8_t reg = Serial.read();
      uint8_t val = Serial.read();

      if (lo == 0xFF && hi == 0xFF && reg == 0xFF && val == 0xFF) {
        inputDone = true;   // 終端マーカー
        break;
      }

      ringDelay[ringTail] = (uint16_t)lo | ((uint16_t)hi << 8);
      ringReg[ringTail] = reg;
      ringVal[ringTail] = val;
      ringTail = (uint8_t)((ringTail + 1) % EVENT_SLOTS);
      ringCount++;
      lastActivity = millis();
    }

    // --- 2. 実行: 待ち時間が来たイベントを処理する ---
    if (ringCount > 0) {
      if (!dueValid) {
        // 次のイベントの実行時刻を、前のイベントの予定時刻から積み上げる。
        // micros()を都度基準にすると誤差が累積してテンポがずれるため。
        dueTime += (uint32_t)ringDelay[ringHead] * 100UL;
        dueValid = true;
      }
      if ((int32_t)(micros() - dueTime) >= 0) {
        uint8_t reg = ringReg[ringHead];
        uint8_t val = ringVal[ringHead];
        ringHead = (uint8_t)((ringHead + 1) % EVENT_SLOTS);
        ringCount--;
        dueValid = false;

        if (reg != 0xFF) {
          if (!dspWrite(reg, val)) {
            driverLost = true;
            break;
          }
        }
        Serial.write(CREDIT_BYTE);
        lastActivity = millis();
      }
    } else if (inputDone) {
      break;
    } else if (millis() - lastActivity > STREAM_STARVE_TIMEOUT_MS) {
      // PC側が落ちた等。鳴りっぱなしを避けて抜ける。
      break;
    }
  }

  if (driverLost) {
    Serial.write(ERR_DRIVER_TIMEOUT);
  } else {
    Serial.write(ACK_STREAM_DONE);
  }
}

// ==================== 従来の .spc 転送コマンド ====================

// リセットパルス幅・ready待ち・再試行回数。
// 長時間再生の後はリセットからの立ち上がりを取りこぼすことがあるため、
// パルスを長めに取り、ファーム内で数回やり直す。
// 合計(3 × (100ms + 2500ms) ≒ 7.8秒)はホスト側のシリアルタイムアウト(10秒)未満に収めること。
const uint16_t RESET_PULSE_MS = 100;
const uint16_t RESET_READY_TIMEOUT_MS = 2500;
const uint8_t RESET_ATTEMPTS = 3;

void handleReset() {
  bool ready = false;
  for (uint8_t attempt = 0; attempt < RESET_ATTEMPTS && !ready; attempt++) {
    digitalWrite(PIN_RESET, LOW);
    delay(RESET_PULSE_MS);
    digitalWrite(PIN_RESET, HIGH);

    uint32_t start = millis();
    while (millis() - start < RESET_READY_TIMEOUT_MS) {
      if (readPort(0) == 0xAA && readPort(1) == 0xBB) {
        ready = true;
        break;
      }
    }
  }

  transferIndex = 0;
  firstBlock = true;
  driverSeq = 0;

  if (ready) {
    Serial.write(ACK_RESET);
  } else {
    Serial.write((uint8_t)0x00);
  }
}

void handleSetAddr() {
  uint8_t buf[3];
  if (!readSerialExact(buf, 3, 5000)) return;
  uint8_t addrLo = buf[0];
  uint8_t addrHi = buf[1];
  bool cont = buf[2] != 0;

  writePort(2, addrLo);
  writePort(3, addrHi);

  if (cont) {
    writePort(1, 0x01);

    if (firstBlock) {
      writePort(0, 0xCC);
      if (!waitForPort(0, 0xCC, 1000)) {
        Serial.write(MARKER_TIMEOUT);
        Serial.write((uint8_t)0xFF);
        Serial.write((uint8_t)0xFF);
        Serial.write((uint8_t)0x00);
        Serial.write(readPort(0));
        return;
      }
      firstBlock = false;
    } else {
      uint8_t kick = (uint8_t)(readPort(0) + 2);
      if (kick == 0) kick++;
      writePort(0, kick);
      if (!waitForPort(0, kick, 1000)) {
        Serial.write(MARKER_TIMEOUT);
        Serial.write((uint8_t)0xFF);
        Serial.write((uint8_t)0xFF);
        Serial.write(kick);
        Serial.write(readPort(0));
        return;
      }
    }

    transferIndex = 0;
    Serial.write(ACK_SETADDR);

  } else {
    writePort(1, 0x00);
    uint8_t kick = (uint8_t)(readPort(0) + 2);
    writePort(0, kick);
    firstBlock = true;
    // ジャンプ先が常駐ドライバの場合、ドライバはACKラッチを0に初期化する。
    // 次のdspWrite()はdriverSeq=1から始まるので必ず値が変わる。
    driverSeq = 0;
    Serial.write(ACK_SETADDR);
  }
}

const uint16_t PING_INTERVAL = 64;

void handleSendBytes() {
  uint8_t lenBuf[2];
  if (!readSerialExact(lenBuf, 2, 5000)) return;
  uint16_t length = lenBuf[0] | (lenBuf[1] << 8);

  Serial.write((uint8_t)0xAB);
  Serial.write((uint8_t)(length & 0xFF));
  Serial.write((uint8_t)((length >> 8) & 0xFF));

  for (uint16_t pos = 0; pos < length; pos++) {
    int16_t vb = serialReadByteBlocking(3000);
    if (vb < 0) {
      Serial.write(MARKER_TIMEOUT);
      Serial.write((uint8_t)(pos & 0xFF));
      Serial.write((uint8_t)((pos >> 8) & 0xFF));
      Serial.write((uint8_t)0x00);
      Serial.write((uint8_t)0x00);
      return;
    }
    uint8_t value = (uint8_t)vb;

    writePort(1, value);
    writePort(0, transferIndex);

    if (!waitForPort(0, transferIndex, 200)) {
      uint8_t actual = readPort(0);
      Serial.write(MARKER_TIMEOUT);
      Serial.write((uint8_t)(pos & 0xFF));
      Serial.write((uint8_t)((pos >> 8) & 0xFF));
      Serial.write(value);
      Serial.write(actual);
      return;
    }

    transferIndex = (uint8_t)(transferIndex + 1);

    bool isLast = (pos == length - 1);
    bool isBoundary = ((pos % PING_INTERVAL) == (PING_INTERVAL - 1));
    if (isBoundary || isLast) {
      Serial.write(MARKER_BYTE_OK);
    }
  }

  Serial.write(ACK_SENDBYTES);
}

void handleReadPort() {
  int16_t portB = serialReadByteBlocking(3000);
  if (portB < 0) return;
  uint8_t val = readPort((uint8_t)portB);
  Serial.write((uint8_t)0x04);
  Serial.write(val);
}

// PCMストリーミング: 受け取ったNバイトを、SPC700のドライバに2バイトずつ($F7=2)、
// 端数は1バイト($F7=1)で書かせる。先にシリアルから全部読んでから送る
// (受信バッファ64バイトを溢れさせないため)。
uint8_t pcmBuf[255];

void handlePcmChunk() {
  int16_t n = serialReadByteBlocking(3000);
  if (n < 0) return;
  if (!readSerialExact(pcmBuf, (uint8_t)n, 3000)) return;
  uint8_t i = 0;
  while (i < (uint8_t)n) {
    uint8_t cnt = ((uint8_t)n - i >= 2) ? 2 : 1;
    writePort(1, pcmBuf[i]);
    if (cnt == 2) writePort(2, pcmBuf[i + 1]);
    writePort(3, cnt);
    driverSeq++;
    writePort(0, driverSeq);
    if (!waitForPort(0, driverSeq, DRIVER_TIMEOUT_MS)) {
      Serial.write(ERR_DRIVER_TIMEOUT);
      return;
    }
    i += cnt;
  }
  Serial.write(ACK_PCMCHUNK);
}

// PCMストリーミング用ドライバへの問い合わせ(3=書き込みポインタ, 4=DSPレジスタ読み出し)。
// シーケンス値はdspWriteと同じdriverSeqを使うので、ホストが直接ポートを叩くのと違ってずれない。
void handleDrvQuery() {
  uint8_t buf[3];
  if (!readSerialExact(buf, 3, 3000)) return;
  writePort(3, buf[0]);
  writePort(1, buf[1]);
  writePort(2, buf[2]);
  driverSeq++;
  writePort(0, driverSeq);
  if (!waitForPort(0, driverSeq, DRIVER_TIMEOUT_MS)) {
    Serial.write(ERR_DRIVER_TIMEOUT);
    return;
  }
  Serial.write(CMD_DRVQUERY);
  Serial.write(readPort(1));
  Serial.write(readPort(2));
}

// ARAMの読み返し検査。ドライバの6番(1バイト読んでポインタを進める)をN回繰り返す。
void handleDrvPeek() {
  int16_t n = serialReadByteBlocking(3000);
  if (n < 0) return;
  writePort(3, 6);
  for (uint8_t i = 0; i < (uint8_t)n; i++) {
    driverSeq++;
    writePort(0, driverSeq);
    if (!waitForPort(0, driverSeq, DRIVER_TIMEOUT_MS)) {
      Serial.write(ERR_DRIVER_TIMEOUT);
      return;
    }
    pcmBuf[i] = readPort(1);
  }
  Serial.write(CMD_DRVPEEK);
  Serial.write(pcmBuf, (uint8_t)n);
}

// 一括受信の確認待ち専用の読み取り。読み取り側の待ち時間を書き込みと同じ短さにする。
// 読み違えても一致するまで読み直すだけなので、速さを優先してよい。
bool waitForPortFast(uint8_t port, uint8_t expected, uint32_t timeoutMs) {
  setDataBusInput();
  selectAddr(port);
  uint32_t start = millis();
  while (millis() - start < timeoutMs) {
    PORTC &= ~(1 << 3);
    delayMicroseconds(WRITE_DELAY_US);
    uint8_t v = busReadData();
    PORTC |= (1 << 3);
    if (v == expected) return true;
  }
  return false;
}

// 一括送信専用の最小限のバス操作。通常の writePort/readPort は安定のため3〜15µs待つが、
// SPC700のポートは本来ns単位で応答するので、ストローブと読み取りの前だけ約1µsにする。
// 配線の状態で必要な待ちが変わるので、CMD_BULKTIMING で実行中に変えられるようにしてある。
uint8_t bulkSetupUs = 3;    // アドレス・データを置いてからストローブまで
uint8_t bulkStrobeUs = 3;   // /WR・/RD を下げている時間
uint8_t bulkHoldUs = 3;     // /WR を上げてから次の操作まで

inline void bulkWrite(uint8_t port, uint8_t val) {
  selectAddr(port);
  busWriteData(val);
  if (bulkSetupUs) delayMicroseconds(bulkSetupUs);
  PORTC &= ~(1 << 2);
  if (bulkStrobeUs) delayMicroseconds(bulkStrobeUs);
  PORTC |= (1 << 2);
  if (bulkHoldUs) delayMicroseconds(bulkHoldUs);
}

inline uint8_t bulkReadPort0() {
  PORTC &= ~(1 << 3);
  if (bulkStrobeUs) delayMicroseconds(bulkStrobeUs);
  uint8_t v = busReadData();
  PORTC |= (1 << 3);
  return v;
}

// 3バイト(またはシーケンス値だけ)を置いて、SPC700がシーケンス値を返すのを待つ。
// 読み違いで先に進むとデータが化けるので、2回続けて一致したら受理とみなす。
uint32_t statRecvUs = 0, statBusUs = 0, statPolls = 0;

bool bulkHandshake(uint8_t seq, const uint8_t *data) {
  setDataBusOutput();
  if (data) {
    bulkWrite(1, data[0]);
    bulkWrite(2, data[1]);
    bulkWrite(3, data[2]);
  }
  bulkWrite(0, seq);
  setDataBusInput();
  selectAddr(0);
  uint32_t start = millis();
  uint8_t hits = 0;
  while (true) {
    statPolls++;
    if (bulkReadPort0() == seq) {
      if (++hits >= 2) return true;
    } else {
      hits = 0;
      if (millis() - start >= DRIVER_TIMEOUT_MS) return false;
    }
  }
}

bool drvHandshakeFast(uint8_t seq) {
  return bulkHandshake(seq, NULL);
}

// PCM一括送信: ドライバを一括受信モード(7)に入れ、3バイトずつ$F5-$F7に置いて渡し、最後に$F4=0で抜ける。
void handlePcmBulk() {
  uint32_t t0 = micros();
  int16_t n = serialReadByteBlocking(3000);
  if (n < 0) return;
  if (!readSerialExact(pcmBuf, (uint8_t)n, 3000)) return;
  uint32_t t1 = micros();
  statRecvUs += t1 - t0;
  if ((uint8_t)n % 3 != 0) {
    Serial.write(ERR_DRIVER_TIMEOUT);
    return;
  }
  writePort(3, 7);
  driverSeq++;
  if (driverSeq == 0) driverSeq = 1;
  if (!drvHandshakeFast(driverSeq)) {
    Serial.write(ERR_DRIVER_TIMEOUT);
    return;
  }
  for (uint8_t i = 0; i < (uint8_t)n; i += 3) {
    driverSeq++;
    if (driverSeq == 0) driverSeq = 1;
    if (!bulkHandshake(driverSeq, pcmBuf + i)) {
      Serial.write(ERR_DRIVER_TIMEOUT);
      return;
    }
  }
  if (!drvHandshakeFast(0)) {
    Serial.write(ERR_DRIVER_TIMEOUT);
    return;
  }
  driverSeq = 0;
  writePort(3, 0);
  statBusUs += micros() - t1;
  Serial.write(CMD_PCMBULK);
}

void writeLE32(uint32_t v) {
  for (uint8_t i = 0; i < 4; i++) Serial.write((uint8_t)(v >> (8 * i)));
}

void handleBulkStats() {
  Serial.write(CMD_BULKSTATS);
  writeLE32(statRecvUs);
  writeLE32(statBusUs);
  writeLE32(statPolls);
  statRecvUs = statBusUs = statPolls = 0;
}

void handleSetBaud() {
  int16_t code = serialReadByteBlocking(3000);
  if (code < 0 || code > 2) return;
  static const uint32_t rates[] = {500000UL, 1000000UL, 2000000UL};
  Serial.write(CMD_SETBAUD);
  Serial.flush();
  Serial.end();
  Serial.begin(rates[code]);
}

void handleBulkTiming() {
  uint8_t buf[3];
  if (!readSerialExact(buf, 3, 3000)) return;
  bulkSetupUs = buf[0];
  bulkStrobeUs = buf[1];
  bulkHoldUs = buf[2];
  Serial.write(CMD_BULKTIMING);
}

void handleWritePort() {
  uint8_t buf[2];
  if (!readSerialExact(buf, 2, 3000)) return;
  writePort(buf[0] & 0x03, buf[1]);
  Serial.write(ACK_WRITEPORT);
}

void handleSetVolume() {
  int16_t dutyB = serialReadByteBlocking(3000);
  if (dutyB < 0) return;
  analogWrite(PIN_VOLUME, (uint8_t)dutyB);
  Serial.write(CMD_SETVOLUME);
  Serial.write((uint8_t)dutyB);
}

void setup() {
  Serial.begin(500000);

  pinMode(ARD_A0, OUTPUT);
  pinMode(ARD_A1, OUTPUT);
  pinMode(PIN_WR, OUTPUT);
  pinMode(PIN_RD, OUTPUT);
  pinMode(PIN_RESET, OUTPUT);
  pinMode(PIN_VOLUME, OUTPUT);

  digitalWrite(PIN_WR, HIGH);
  digitalWrite(PIN_RD, HIGH);
  digitalWrite(PIN_RESET, HIGH);
  analogWrite(PIN_VOLUME, 0);

  setDataBusInput();
}

void loop() {
  uint8_t cmd = serialReadByteForever();

  switch (cmd) {
    case CMD_RESET:     handleReset();     break;
    case CMD_SETADDR:   handleSetAddr();   break;
    case CMD_SENDBYTES: handleSendBytes(); break;
    case CMD_READPORT:  handleReadPort();  break;
    case CMD_SETVOLUME: handleSetVolume(); break;
    case CMD_DSPWRITE:  handleDspWrite();  break;
    case CMD_STREAM:    handleStream();    break;
    case CMD_PANIC:     handlePanic();     break;
    case CMD_PING:      handlePing();      break;
    case CMD_WRITEPORT: handleWritePort(); break;
    case CMD_PCMCHUNK:  handlePcmChunk();  break;
    case CMD_DRVQUERY:  handleDrvQuery();  break;
    case CMD_DRVPEEK:   handleDrvPeek();   break;
    case CMD_PCMBULK:   handlePcmBulk();   break;
    case CMD_BULKTIMING: handleBulkTiming(); break;
    case CMD_SETBAUD:   handleSetBaud();   break;
    case CMD_BULKSTATS: handleBulkStats(); break;
    default: break;
  }
}

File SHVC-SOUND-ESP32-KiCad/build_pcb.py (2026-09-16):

"""
ESP32版 SHVC-SOUND 基板(74.09 x 66.5mm、SHVC-SOUNDモジュールと同じ外形)を組み立てる。

  KiCad付属のpythonで実行:
    "C:\\Program Files\\KiCad\\10.0\\bin\\python.exe" build_pcb.py place   … 部品配置だけ(配線なし)
    "C:\\Program Files\\KiCad\\10.0\\bin\\python.exe" build_pcb.py import  … Freeroutingの結果(.ses)を取り込みGNDベタを貼る

  上面(F)  : SHVC-SOUND モジュールのコネクタ J4 だけ(モジュールはこの面に部品面を下にして載る)
  裏面(B)  : それ以外すべて(ESP32 DevKitC はソケット、DIP IC、アンプ回路、ジャック、電源入力)
  外形とJ4の位置は OpenSFC TCMK-77XR(SHVC-SOUND 互換モジュール)の基板データを裏返して求めた。
"""
import json
import math
import os
import re
import sys

import pcbnew

HERE = os.path.dirname(os.path.abspath(__file__))
NAME = "SHVC-SOUND-ESP32"
PCB = os.path.join(HERE, NAME + ".kicad_pcb")
KICAD_FP = os.environ.get("KICAD10_FOOTPRINT_DIR", r"C:\Program Files\KiCad\10.0\share\kicad\footprints")

OX, OY = 100.0, 100.0          # 基板左上の座標
W, H = 74.09, 66.5
MM = pcbnew.FromMM

# (リファレンス, 面, 回転, 位置合わせに使うパッド, 上から見た位置x, y)
# 裏面の部品は左右反転するので、「そのパッドが来る場所」で指定する
PLACEMENT = [
    ("J4", "F", 180, None, 55.40, 6.59),
    ("U1", "B", 180, "1", 4.00, 39.56),          # USB側が上辺。1-15番列が x=4、16-30番列が x=29.4
    ("U3", "B", 0, "1", 20.50, 9.00),           # ESP32の下(ソケットの高さぶんの隙間)に入れる
    ("C9", "B", 0, "1", 12.00, 5.50),
    ("R7", "B", 0, "1", 21.00, 40.60),
    ("R8", "B", 0, "1", 21.00, 43.70),
    ("R9", "B", 0, "1", 21.00, 46.80),
    ("C12", "B", 0, "1", 37.50, 5.00),
    ("U7", "B", 270, "1", 10.50, 57.00),         # 12V→5V DC-DC(7805互換 SIP3)
    ("D1", "B", 0, "1", 10.62, 44.00),         # U7本体(基板内側へ倒す)の場所を空ける
    ("C13", "B", 0, "1", 4.80, 54.00),        # DC-DCの左(表から見て)、固定穴の上
    ("U2", "B", 0, "1", 43.62, 14.50),
    ("U4", "B", 0, "1", 56.12, 14.50),
    ("C8", "B", 0, "1", 38.50, 11.30),
    ("C10", "B", 0, "1", 51.00, 11.30),
    ("C11", "B", 0, "1", 67.50, 18.50),
    ("C6", "B", 0, "1", 53.50, 41.50),
    ("C7", "B", 0, "1", 53.50, 45.00),
    ("C3", "B", 0, "1", 61.50, 38.00),
    ("C4", "B", 0, "1", 71.30, 38.00),
    ("U6", "B", 0, "1", 43.62, 43.00),
    ("R6", "B", 0, "1", 72.50, 27.50),
    ("R5", "B", 0, "1", 72.50, 31.50),
    ("C5", "B", 0, "1", 62.00, 43.00),
    ("R10", "B", 0, "1", 72.50, 47.50),
    ("R1", "B", 0, "1", 55.62, 49.00),
    ("R2", "B", 0, "1", 55.62, 52.50),
    ("C1", "B", 0, "1", 49.75, 60.50),
    ("C2", "B", 0, "1", 56.75, 60.50),
    ("J1", "B", 0, None, 66.70, 59.10),        # 差し込み口が右辺から外に向く,
    ("J3", "B", 0, None, 24.00, 53.00),        # 12V入力(PDモジュール)。実物合わせで上へ8mm
]
# モジュール側の穴(TCMK-77XR の Edge.Cuts の円)を裏返した位置 (x, y, 直径)
HOLES = [(5.36, 62.06, 3.96), (10.84, 62.06, 2.98)]

# +12V はアンプの消費(数十mA)だけなので細線でよい(遠い左下のJ3から引き回すため)
POWER_NETS = ["GND", "+5V", "+3V3", "AMP_VP", "AMP_OUT_L", "AMP_OUT_R", "OUT_L_RC", "OUT_R_RC",
              "JACK_L", "JACK_R"]


def write_project():
    path = os.path.join(HERE, NAME + ".kicad_pro")
    pro = json.load(open(path, encoding="utf-8")) if os.path.exists(path) else {}
    pro.setdefault("meta", {"filename": NAME + ".kicad_pro", "version": 3})
    base = {"clearance": 0.2, "track_width": 0.25, "via_diameter": 0.7, "via_drill": 0.35,
            "microvia_diameter": 0.3, "microvia_drill": 0.1, "diff_pair_width": 0.2, "diff_pair_gap": 0.25,
            "diff_pair_via_gap": 0.25, "wire_width": 6, "bus_width": 12, "line_style": 0, "pcb_color": "rgba(0, 0, 0, 0.000)",
            "schematic_color": "rgba(0, 0, 0, 0.000)", "priority": 2147483647}
    pro["net_settings"] = {
        "classes": [dict(base, name="Default"),
                    dict(base, name="Power", track_width=0.6, via_diameter=0.9, via_drill=0.45, priority=0)],
        "meta": {"version": 4},
        "netclass_patterns": [{"netclass": "Power", "pattern": n} for n in POWER_NETS],
    }
    json.dump(pro, open(path, "w", encoding="utf-8"), indent=2)


def sexpr(text):
    tokens = re.findall(r'\(|\)|"(?:\\.|[^"\\])*"|[^\s()]+', text)
    stack, cur = [], []
    for t in tokens:
        if t == "(":
            stack.append(cur)
            cur = []
        elif t == ")":
            done, cur = cur, stack.pop()
            cur.append(done)
        else:
            cur.append(t[1:-1] if t.startswith('"') else t)
    return cur[0]


def child(node, key):
    return [c for c in node if isinstance(c, list) and c and c[0] == key]


PIN_FUNCTIONS = {}


def parse_netlist():
    root = sexpr(open(os.path.join(HERE, NAME + ".net"), encoding="utf-8").read())
    comps = {}
    for c in child(child(root, "components")[0], "comp"):
        comps[child(c, "ref")[0][1]] = (child(c, "value")[0][1], child(c, "footprint")[0][1])
    pads = {}
    for n in child(child(root, "nets")[0], "net"):
        name = child(n, "name")[0][1].lstrip("/")
        for node in child(n, "node"):
            pads[(child(node, "ref")[0][1], child(node, "pin")[0][1])] = name
            pf = child(node, "pinfunction")
            if pf:
                PIN_FUNCTIONS[(child(node, "ref")[0][1], child(node, "pin")[0][1])] = re.sub(r"_\d+$", "", pf[0][1])
    return comps, pads


def load_fp(fpid):
    lib, name = fpid.split(":")
    path = os.path.join(HERE, lib + ".pretty") if lib == "SHVC-ESP32" else os.path.join(KICAD_FP, lib + ".pretty")
    fp = pcbnew.FootprintLoad(path, name)
    if fp is None:
        raise RuntimeError(f"フットプリントが見つからない: {fpid}")
    fp.SetFPID(pcbnew.LIB_ID(lib, name))
    return fp


def pad_pos(fp, num):
    for p in fp.Pads():
        if p.GetNumber() == num:
            return p.GetPosition()
    raise KeyError(num)
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

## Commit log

2026-08-17 Initial commit: SHVC-SOUND スタンドアロンプレイヤー
    基板設計(KiCad)とSPC再生ソフト一式。
    spc_uploader.ino を Arduino Nano 向けに書き直し、SPC700 IPL ROM の
    転送プロトコルを実装した:
    - 最初のブロックは port1=非ゼロ + port0=$CC のキックで開始
    - 2ブロック目以降は「直前にport0へ書いた値+2」で切り替え(ゼロ回避付き)
    - ジャンプは port1=0 + port0=直前値+2 で発火
    - バイトカウンタはブロックごとに0へ振り直す
    spc_play.py の復元スタブで、FLG($6C)へ先に$20(エコー書き込み禁止)を
    書くよう修正。ESA/EDL設定前にエコーが有効化されARAMを破壊す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
    [SHVC-SOUND-KiCad.kicad_pcb, SHVC-SOUND-KiCad.kicad_sch]
2026-08-17 実機切り分け用の自己診断スケッチと最小構成手順を追加
    音が出ない原因を切り分けられないので、PCのPythonを介さず
    Arduino単体でSHVC-SOUNDからノイズを鳴らす自己診断を追加した。
    hw_selftest.ino は IPL ROM起動確認 → 1ブロック目転送 → 2ブロック目転送
    → 実行コード転送 → ジャンプ の5段階を個別に判定し、落ちた段階ごとに
    疑うべき配線を出力する。ノイズが鳴ればハードは完動と確定できる。
    BRRサンプル($03 = END|LOOP)とサンプルディレクトリも転送するため、
    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
2026-08-17 マイコンをUno R3にも対応(ドキュメントをボード非依存に)
    Uno R3とNanoはどちらもATmega328P・16MHz・5Vロジックで、
    使用するD2-D9 / A0-A4 / D10のピン名も同一のため、
    スケッチと配線は変更なしでそのまま動く。
    基板側はArduino Nanoフットプリントのままなので、
    Uno R3を基板に載せる場合は要変更である旨をREADMEに追記。
2026-08-17 A4印刷用の配線表PDFを追加
    作業台で使う前提の実作業用シート。全17本にチェックボックスを付け、
    配線しながら1本ずつ潰せるようにした。2ページ目は診断結果の読み方。
    wiring-sheet.html をソースとし、Chromeのヘッドレス印刷でPDF化している
    (BIZ UDPGothicをサブセット埋め込み、A4 595x842pt)。
2026-08-17 1番ピンの確定手順を追加
    24pinコネクタはキーが無く逆挿しできるうえ、ベンダー提供の
    フットプリントもパッド24個すべてが丸で1番マーカーが無いため、
    物理的な手がかりが存在しない。
    代わりにGND(pin19/23)の配置が非対称であることを使い、テスターの
    導通モードだけで向きを一意に確定できる手順を追加した。
    GND 2本は同じ列で間に1本(pin21)を挟んで並び、片方が端に来る。
    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
2026-08-17 配線表をSHVC-SOUND側pin1→24の結線表形式に作り直し
    従来は「電源/固定ピン/バス」でカテゴリ分けしていたため、
    コネクタを上から順に配線していく実作業とは並びが一致せず
    参照しづらかった。
    pin1から24まで通し番号で並べ、各行に signal / 種別 / 接続先を
    記載する形に変更。未接続のpin16・17もグレーアウトで明示し、
    抜け漏れが無いことを一覧で確認できるようにした。
2026-08-17 実機での動作確認完了、spc_play.pyにマスター音量ブースト機能を追加
    Arduino UNO(arduino:avr:uno, COM4)で hw_selftest.ino を実行し
    全項目OK・ノイズ再生を確認。これによりハード面(配線・IPL ROM転送
    プロトコル)は完動と確定した。
    なお hw_selftest.ino / spc_uploader.ino には、変数名 PIN_A0 / PIN_A1 が
    Arduino AVRコアのマクロ #define PIN_A0 (14) と衝突しコンパイルエラーに
    なる不具合があったため ARD_A0 / ARD_A1 に改名して修正。
    続けて spc_uploader.ino を書き込み、song.spc の実機再生に成功。
    転送(RAM 65216バイト+復元スタブ811バイト)はエラーなく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
    [hw_selftest.ino, spc_play.py, spc_uploader.ino]
2026-08-17 音量ブーストが効いていなかった原因を修正: マスターだけでなく各ボイスも底上げ
    --volume 1.3 を試しても体感で変化が無いとの報告を受け、実際に
    song.spc のDSPレジスタを読んで原因を特定した。
    MVOLL/MVOLRは既に0x7F(127、符号付き8bitの最大値)だった。
    boost_master_volume() はそこをsigned 8bitでクランプする実装なので、
    1.3倍しても127のまま変化せず、ブーストが完全に無意味になっていた。
    実際に音量を支配していたのは各ボイスのVOLL/VOLR(鳴っていた
    voice0/1/3で6〜36程度、最大127に対してかなり低い値)だったため、
    boost_mas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
    [spc_play.py]
2026-08-17 アンプ段のPWM音量制御を追加(TDA7053A VC1/VC2向け)
    DSPレジスタでの音量ブースト(--volume)はボイス個別ゲインを上げる形
    なので、DSP内部ミキシングでクリップしやすく歪み・ノイズ感が増える
    という実機での指摘を受けた。PROJECT_BRIEF本来の設計であるアンプ段
    (TDA7053A VC1/VC2)でのアナログゲイン調整に対応する。
    D10は/MUTE用に確保していたが、配線表では/MUTEを+5V直結にする案内に
    既にしていたためD10を解放しPWM音量出力に転用した。
    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
2026-08-17 GUIアプリ(Tkinter)とROM解析モジュールを追加
    spc_gui.py: 非HTMLのデスクトップGUI。Python標準のTkinterのみで実装し
    追加インストール不要。プレイリスト管理、ID666タグ表示、DSP/アンプ音量
    スライダー、進捗バー、ログ、曲長による自動送りを実装。
    転送は約30秒かかるためワーカースレッドで実行し、queue経由でUIへ通知する
    (TkinterはスレッドセーフでないためUI更新は必ずメインスレッドで行う)。
    転送中止用に cancelled コールバックを追加。
    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
2026-08-17 転送プロトコルを最適化、65KB転送を37.8秒から6.7秒に短縮
    連続再生時「曲の切れ目でいちいち待ちたくない」との要望を受けて調査。
    次の曲を裏で先に送っておくことは、ARAMが1つしか無く現在再生中の
    曲のコード・データを共有しているため原理的に不可能(書き込んだ瞬間に
    再生中の音が止まる)。加えてIPL ROMへ戻る/RESETが必須なプロトコル上、
    待たずに先読みする余地も無い。
    そのため実質的な唯一の対策である転送そのものの高速化に着手し、
    実機計測で3段階、合計5.6倍の短縮を達成した:
    1. spc_uploader.ino の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
    [spc_play.py, spc_uploader.ino]
2026-08-17 高速化後に無音化した不具合を修正: バスタイミングのマージン不足
    転送プロトコル最適化(直接ポート操作化・65KB転送37.8s→6.7s)の後、
    転送は毎回エラーなく完走するのに実際には音が出なくなる不具合が発生した。
    原因はIPL ROMのACK機構がデータの中身ではなくカウンタの一致だけを
    見ているため、実際のデータバイトが化けていても「成功」と報告されて
    しまう構造にあった。digitalWrite()版は1回の呼び出しだけで数マイクロ秒
    かかる重い実装だったため、明示的なdelayMicroseconds(1)以上の
    「余分な余裕」がバスタイ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
    [spc_uploader.ino]
2026-08-17 Androidアプリ開発の環境構築ガイドを追加
    PCを完全に不要にし、スマホ(Android)とArduinoをUSB直結して
    spc_play.py相当のロジックをアプリ側に持たせる方針で進めることになった。
    Arduino側ファームウェア(spc_uploader.ino)は変更不要、既に実機検証済みの
    プロトコルをそのまま使う想定。
    この開発環境にはJava/Android SDK/adbが一切無く、Androidアプリの
    ビルド・実機検証がこの場ではできないことをユーザーに開示した上で、
    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
2026-08-17 Androidアプリ: SpcFile/SpcController/StubBuilderをKotlinへ移植、ビルド確認済み
    PCを完全に不要にし、Android端末とArduinoをUSB直結してspc_play.py相当の
    ロジックをアプリ側に持たせる方針で進めている。Arduino側ファームウェア
    (spc_uploader.ino)は変更しない。
    SpcFile.kt: .spcファイルのヘッダ解析・ID666タグ読み取り(Python版と同一オフセット)。
    SpcController.kt: Arduinoとの通信プロトコル。CMD/ACK定数・PING_INTERVAL(64)・
    ボーレート(500000)をspc_uploader.inoと完全一致させている。
    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
2026-08-18 GUIをPyInstallerでexe化、Androidアプリの最終版をpush
    .gitignore: PyInstallerのビルド成果物(dist/, build_tmp/, *.spec)を除外。
    容量が大きく、ソースから再生成できるためコミットしない。
    SHVC-SOUND-Android: 実機で動作確認まで完了した最終版を反映(前回コミットでは
    未pushだった)。MainActivity.kt・Player.kt・レイアウトを追加、SpcController.ktは
    以下を修正:
    - USB権限リクエストのPendingIntentをAndroid 14対応(setPackageで明示的インテント化)
    - 受信をport.read()の同期ポーリングからSerialInputOutputManager方式に変更
    (機種によって同期方式だと2回目以降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
2026-08-18 MIDIをSHVC-SOUND(SPC700/S-DSP)で鳴らすツール midi2spc を追加 (#1)
    MIDIをS-DSPのレジスタ操作イベント列に変換し、PC上のソフトウェアモデルと
    実機のSHVC-SOUNDの両方で鳴らせるようにした。
    構成:
    smf.py 依存ライブラリなしのSMFパーサ
    brr.py BRR(4bit ADPCM)エンコーダ/デコーダ
    instruments.py 音色バンク20種(BRR実エンコード)とGMマップ
    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
2026-09-13 実機再生の安定化と、密なMIDIを8ボイスで鳴らすための改善 (#2)
    * spc_realtime: 接触不良に強いバスタイミングとリセット処理にする
    - 読み取りだけ待ち時間を15µsに延長(書き込みは3µsのまま)。
    書き込みのみの転送は化けないが、SPC700からの読み戻しが不安定だったため。
    両方延ばすと密な曲でDSP書き込みが追いつかずテンポが遅れた
    - 常駐ドライバの応答待ちを20ms→100msに延長
    - リセットパルスを100msにし、ready待ち2.5秒×最大3回までファーム内で再試行
    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
2026-09-13 録音をそのまま鳴らすBRRストリーミング再生と、自動採譜ツールを追加 (#3)
    * spc_realtime: BRRストリーミング用のコマンドを追加
    - CMD_PCMCHUNK(0x0C): 最大255バイトを受け取り、SPC700上のPCMドライバへ
    2バイトずつ($F7=2)、端数は1バイト($F7=1)で書かせる
    - CMD_DRVQUERY(0x0D): ドライバのコマンドを引数2つで実行し、$F5/$F6を返す
    (ポインタ設定・問い合わせ、DSPレジスタ読み出し)
    - CMD_DRVPEEK(0x0E): ARAMをNバイト読み返す(データ化けの検査用)
    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
2026-09-16 PCMストリーミングの高速化・ミッド/サイドのステレオ再生・試聴用ツールを追加
    - spc_realtime.ino: 3バイト一括ハンドシェイク転送(CMD_PCMBULK)、転送タイミング設定、
    ボーレート切替、転送統計コマンドを追加(8.7KB/s → 15.2KB/s)
    - pcm_stream.py: ドライバにリング切替・一括受信モードを追加し、ディレクトリを$F700へ移動。
    フィルタ0の高速BRRエンコード、--filter0/--peak/--benchmark 等のオプション
    - pcm_stereo.py: ミッド(16kHz)/サイド(6kHz)の2ボイスでステレオ録音をストリーミング再生
    - listen.py / mic_check.py / record_play.py: USBマイクで実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
2026-09-16 ESP32版の回路図・基板(r0.3)と、製作用の出力スクリプトを追加
    SHVC-SOUNDモジュールの背面にぴったり付く 74.09×66.5mm・2層基板。
    ESP32 DevKit V1(30ピン) + 74HCT541N×2 + 74LVC245N でバスをレベル変換し、
    TDA7053Aでヘッドホンを鳴らす。電源はUSB-PD(12V)ひとつで、7805互換DC-DCで5Vを作る。
    - gen_schematic.py: 回路図(SHVC-SOUND-ESP32.kicad_sch)を生成
    - build_pcb.py / route.py: 部品配置 → Freeroutingで自動配線 → GNDベタ
    - print_fit_check.ps1 / dump_geom.py: 現物合わせ用のA4原寸シートを印刷
    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
    [SHVC-SOUND-ESP32.kicad_pcb, SHVC-SOUND-ESP32.kicad_sch, dcdc_sip3.step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]
